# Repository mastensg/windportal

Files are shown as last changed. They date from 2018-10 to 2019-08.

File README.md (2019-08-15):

# Windportal
An interactive installation demonstrating the power of the wind.

The machine simulates the wind conditions at the Hywind off-shore windmill part in Scotland.
Live data about current windspeed conditions are fetched, and the audience can press a button
to experience this wind-power blowing in their face.

Developed for Equinor in collaboration with ad-agency [Dept](http://dept.no).

[More info, pictures and video](https://dept.no/project/equinor-wind-portal)

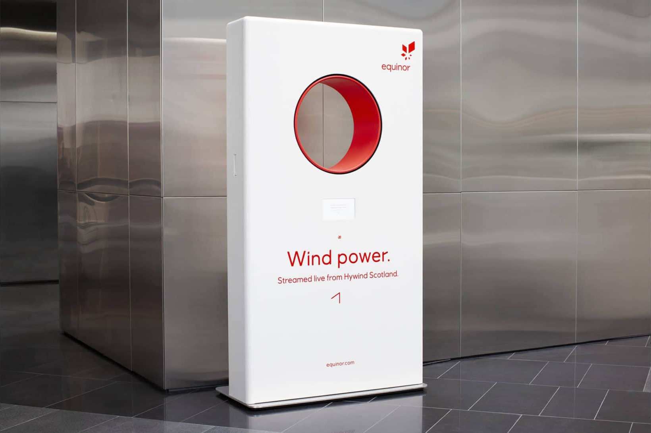
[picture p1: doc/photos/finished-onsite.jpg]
Finished windportal


## Contents
This repo contains the software and electronics of the system,
developed by Martin Stensgård and [Jon Nordby](http://jonnor.com).

A previous iteration can be found at [jonnor/windportal](https://github.com/jonnor/windportal).

## License
[ISC](./LICENSE.md)

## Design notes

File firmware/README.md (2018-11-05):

## SSH config
To jump via the central cloud server.

    Host windhub
	    HostName hub.wind.mastensg.net
	    User jonnor
    
    Host wind0
     	User jonnor
    #	HostName  dlock-dev.local
	    ProxyCommand=ssh windhub nc localhost 2000

## Initalize device from base image

On first run you need to use default `pi` user. This should only be done on a private Ethernet connection.

    ansible-playbook display.yml -l display0 --user pi --ask-pass

Afterwards the SSH keys are in place

    ansible-playbook display.yml -l display0

## Flash base image

    gunzip -c display0-raspbian.img | sudo dd of=/dev/MYSCARD status=progress oflag=sync bs=1M

## Make base image
To make something flashable of a known size (under 4GB) with a known hostname.

* Download Raspbian https://www.raspberrypi.org/downloads/raspbian/
* Flash onto SD card `unzip -p raspbian_lite_latest 2018-10-09-raspbian-stretch-lite.img | dd of=/dev/MYCARD bs=1M`
* Mount `/` filesytem, change hostname and hosts to `display0`
* Enable workstation in `/etc/avahi-daemon.conf`: `publish-workstation=yes`
* Mount `/boot` filesyste. Add empty `ssh` file to enable SSH
* Add `enable_uart=1` and `dtoverlay=pi3-disable-bt` to `/boot/config.txt` for serial console
* Put SDCard into RPi, connect Ethernet cable to PC
* Boot RPi, check that you can SSH into it `ssh pi@display0.local`
* Check that automatic partition resizing was completed
* Turn of RPI, put SDcard into PC
* Resize root filesystem to 3000M with `resize2fs`
* Resize root partition to 3100M with `cfdisk`
* Make image using `dd if=/dev/mmcblk1 conv=sync,noerror bs=1M count=8k | gzip -c > display0-raspbian.img.gz`

## Environment variables

Some programs require variables to be set to work.

    MSGFLO_BROKER={{display_broker_url}}
    DISPLAY_PREFIX=display/{{ansible_hostname}}
    WP_FONT_PATH=/opt/windmachine/equinor_fonts/Equinor-Medium.otf

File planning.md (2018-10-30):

Key questions

- [x] OK with FOSS (Sjur)
- [x] Fan control interface. Analog or modbus
- [x] Decide display. LCD, dial indicator or 7-segment.
- [x] Get a custom domain (dep: Sjur) `windportal.dept.no`
- [ ] Ownership server,SIM (dep: Sjur)

Risk moments

- Interfacing fan,display
- Data communication device,server,datasource
- In-field failures

Bugs

- [ ] If Arduino is unplugged, wp_firmata keeps running using 100% CPU.
- [ ] ssh-call-home sometimes hangs, does not reconnect after network or server disconnect

Tools

- [ ] CLI for sending IPC message `wp_ipc KEY VALUE`

## Deadlines

### Tuesday 16 October
- Specification frozen.
- Decided display type
- All electronics/hardware ordered.

## Done

Kickoff

- [x] Estimate hours / cost for project

Milestone 0: Ready to work

- [x] Copy Ansible skeleton (J) 5
- [x] Setup RPi3b+ base (J)
- [x] Setup firmware base (J)
- [x] Setup server. Linode,DNS,email,Mosquitto in Ansible (M) 5
- [x] Server is deployed

RPI ready

- [x] RPI automatically sets up reverse SSH (J)
- [x] Setup/test 3G modem on RPI (J)
- [x] Device can fetch current wind data from server (J)
- [x] Test Firmata at same time as ModemManager, ttyACMx. (J)

Milestone FANCONTROL:

- [x] Tested control of fan from software (via Firmata, analog/PWM) 

Control panel

- [x] Status LEDs
- [x] Potmeter animation scale
- [x] Potmeter manual fan control
- [x] Software/manual switch

Milestone B: All electronics assembled (M)

- [x] Baseboard for mounting in box
- [x] Optocoupler for fancontrol. Non-inverting
- [x] USB to serial in dashboard
- [x] RPi powered and running
- [x] Arduino with daughterboard
- [x] Display connected
- [x] Fan power module connected

## TODO

### System check, Oct 23

Documentation

- [x] Make block diagram of electronics

Windgust animation

- [x] First version. Should depend on (average) windspeed
- [x] Move animation to dedicated program (J)
- [x] systemd/Ansible for services (J)

Display:

- [x] Test servocontrol for dial type display. Incl a simple hand. (M)
- [x] Screen tested OK
- [x] Program to display windspeed

Milestone C: I/O complete, from RPi (M)

- [x] Get adjust potentiometer (power level)
- [x] Set fan power
- [x] Show text on display

Server datafetching

- [x] Define MQTT interface (J)
- [x] Server fetches data using YR (J) 3
- [x] Fetch data using scraped HTML page (J) 3
- [x] Deploy data fetcher to hub

## Assembly, Friday Oct 26

Electronics

- [x] Buy power supplies. 5V + 12V
- [x] Buy enclosure(s) PSU
- [x] Buy Wago connectors
- [x] Use cable glands on wires
- [x] Add USB powered hub
- [x] Solder the serial console connection

User button

- [x] Test user button input
- [x] Firmata: get user button status (turn on)
- [x] Scale gusts based on user input

Display

- [x] Add wind description label "frisk bris" under windspeed
- [x] Add a small variation to shown windspeed
- [ ] Hide startup rainbow, linux messages from screen
- [ ] Hide low-power symbol

## Tuneup

Bugs

- [ ] Firmata process sometimes hangs.
Possibly due to blocking write() call if discovery is not successful.
Use systemd watchdog to make sure it restarts. https://stackoverflow.com/a/37111518/1967571

Monitoring

- [ ] Turn status LEDs in panel on/off
- [ ] Log 4G status. Signal strength, network type, connected/not
- [ ] Log undervoltage condition. Ideally voltage level, or just dmesg warnings
- [ ] Device reports heartbeat to server on MQTT (`fbp`)
- [ ] Server stores heartbeat events

System complete checklist

- [ ] Windgust animation works
- [ ] Monitoring exists
- [ ] Tested device poweroffs
- [ ] Tested device disconnect/reconnect
- [ ] Tested server downtime, recovers automatically
- [ ] Tested windpower override switch

## Failure modes

- I/O failure. Software does right thing, but right action does not happen
- RPi fails to fetch server. 3G connection, HTTP error, server down
- [...]

## Worklog

Date,person,hours,area

    02.10.2018,jon,8,planning
    02.10.2018,martin,8,planning
    03.10.2018,jon,2,firmware
    07.10.2018,jon,4,firmware
    09.10.2018,jon,1,planning
    09.10.2018,jon,4,io

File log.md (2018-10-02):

- [ ] hvilke servo-motorer? hvor mye dreiemoment?

--------------------------------  2018-10-02  --------------------------------

møte hos adep
- martin
- jacob
- sjur
- petter
- jonnor

--------------------------

hvor mye dreiemoment?

vi kan teste med 5.5 kgcm servo

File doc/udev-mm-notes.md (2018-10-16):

## serial device internal on RPI

jonnor@display0:~ $ udevadm info -a --name /dev/ttyAMA0

Udevadm info starts with the device specified by the devpath and then
walks up the chain of parent devices. It prints for every device
found, all possible attributes in the udev rules key format.
A rule to match, can be composed by the attributes of the device
and the attributes from one single parent device.

  looking at device '/devices/platform/soc/3f201000.serial/tty/ttyAMA0':
    KERNEL=="ttyAMA0"
    SUBSYSTEM=="tty"
    DRIVER==""

  looking at parent device '/devices/platform/soc/3f201000.serial':
    KERNELS=="3f201000.serial"
    SUBSYSTEMS=="amba"
    DRIVERS=="uart-pl011"
    ATTRS{driver_override}=="(null)"
    ATTRS{id}=="00241011"
    ATTRS{irq0}=="87"

  looking at parent device '/devices/platform/soc':
    KERNELS=="soc"
    SUBSYSTEMS=="platform"
    DRIVERS==""
    ATTRS{driver_override}=="(null)"

  looking at parent device '/devices/platform':
    KERNELS=="platform"
    SUBSYSTEMS==""
    DRIVERS==""

    jonnor@display0:~ $ udevadm info --query=property /dev/ttyAMA0
    DEVLINKS=/dev/serial1
    DEVNAME=/dev/ttyAMA0
    DEVPATH=/devices/platform/soc/3f201000.serial/tty/ttyAMA0
    ID_MM_CANDIDATE=1
    MAJOR=204
    MINOR=64
    SUBSYSTEM=tty
    TAGS=:systemd:
    USEC_INITIALIZED=3899475

## Arduino Leonardo

jonnor@display0:~ $ udevadm monitor
monitor will print the received events for:
UDEV - the event which udev sends out after rule processing
KERNEL - the kernel uevent

KERNEL[785.479930] add      /devices/platform/soc/3f980000.usb/usb1/1-1/1-1.3 (usb)
KERNEL[785.481021] add      /devices/platform/soc/3f980000.usb/usb1/1-1/1-1.3/1-1.3:1.0 (usb)
KERNEL[785.481991] add      /devices/platform/soc/3f980000.usb/usb1/1-1/1-1.3/1-1.3:1.1 (usb)
UDEV  [785.510745] add      /devices/platform/soc/3f980000.usb/usb1/1-1/1-1.3 (usb)
UDEV  [785.521791] add      /devices/platform/soc/3f980000.usb/usb1/1-1/1-1.3/1-1.3:1.1 (usb)
KERNEL[785.526125] add      /module/cdc_acm (module)
KERNEL[785.528409] add      /devices/platform/soc/3f980000.usb/usb1/1-1/1-1.3/1-1.3:1.0/tty/ttyACM0 (tty)
KERNEL[785.528593] add      /bus/usb/drivers/cdc_acm (drivers)
UDEV  [785.528899] add      /devices/platform/soc/3f980000.usb/usb1/1-1/1-1.3/1-1.3:1.0 (usb)
UDEV  [785.530816] add      /module/cdc_acm (module)
UDEV  [785.535533] add      /bus/usb/drivers/cdc_acm (drivers)
UDEV  [785.541592] add      /devices/platform/soc/3f980000.usb/usb1/1-1/1-1.3/1-1.3:1.0/tty/ttyACM0 (tty)
^Cjonnor@display0:~ $ udevadm info -a --name /dev/ttyACM0 --query=all
P: /devices/platform/soc/3f980000.usb/usb1/1-1/1-1.3/1-1.3:1.0/tty/ttyACM0
N: ttyACM0
S: serial/by-id/usb-Arduino_LLC_Arduino_Leonardo-if00
S: serial/by-path/platform-3f980000.usb-usb-0:1.3:1.0
E: DEVLINKS=/dev/serial/by-id/usb-Arduino_LLC_Arduino_Leonardo-if00 /dev/serial/by-path/platform-3f980000.usb-usb-0:1.3:1.0
E: DEVNAME=/dev/ttyACM0
E: DEVPATH=/devices/platform/soc/3f980000.usb/usb1/1-1/1-1.3/1-1.3:1.0/tty/ttyACM0
E: ID_BUS=usb
E: ID_MM_CANDIDATE=1
E: ID_MODEL=Arduino_Leonardo
E: ID_MODEL_ENC=Arduino\x20Leonardo
E: ID_MODEL_FROM_DATABASE=Leonardo (CDC ACM, HID)
E: ID_MODEL_ID=8036
E: ID_PATH=platform-3f980000.usb-usb-0:1.3:1.0
E: ID_PATH_TAG=platform-3f980000_usb-usb-0_1_3_1_0
E: ID_REVISION=0100
E: ID_SERIAL=Arduino_LLC_Arduino_Leonardo
E: ID_TYPE=generic
E: ID_USB_CLASS_FROM_DATABASE=Miscellaneous Device
E: ID_USB_DRIVER=cdc_acm
E: ID_USB_INTERFACES=:020200:0a0000:
E: ID_USB_INTERFACE_NUM=00
E: ID_USB_PROTOCOL_FROM_DATABASE=Interface Association
E: ID_VENDOR=Arduino_LLC
E: ID_VENDOR_ENC=Arduino\x20LLC
E: ID_VENDOR_FROM_DATABASE=Arduino SA
E: ID_VENDOR_ID=2341
E: MAJOR=166
E: MINOR=0
E: SUBSYSTEM=tty
E: TAGS=:systemd:
E: USEC_INITIALIZED=785540456

jonnor@display0:~ $ udevadm info -a --name /dev/ttyACM0

## Not connecting

Oct 16 18:10:15 display0 ModemManager[297]: <info>  Simple connect started...
Oct 16 18:10:15 display0 ModemManager[297]: <info>  Simple connect state (4/8): Wait to get fully enabled
Oct 16 18:10:15 display0 ModemManager[297]: <info>  Simple connect state (5/8): Register
Oct 16 18:10:15 display0 ModemManager[297]: <info>  Simple connect state (6/8): Bearer
Oct 16 18:10:15 display0 ModemManager[297]: <info>  Simple connect state (7/8): Connect
Oct 16 18:10:15 display0 ModemManager[297]: <info>  Modem /org/freedesktop/ModemManager1/Modem/1: state changed (registered -> connecting)
Oct 16 18:10:15 display0 ModemManager[297]: <warn>  (ttyUSB1): port attributes not fully set

Udevadm info starts with the device specified by the devpath and then
walks up the chain of parent devices. It prints for every device
found, all possible attributes in the udev rules key format.
A rule to match, can be composed by the attributes of the device
and the attributes from one single parent device.

  looking at device '/devices/platform/soc/3f980000.usb/usb1/1-1/1-1.3/1-1.3:1.0/tty/ttyACM0':
    KERNEL=="ttyACM0"
    SUBSYSTEM=="tty"
    DRIVER==""

  looking at parent device '/devices/platform/soc/3f980000.usb/usb1/1-1/1-1.3/1-1.3:1.0':
    KERNELS=="1-1.3:1.0"
    SUBSYSTEMS=="usb"
    DRIVERS=="cdc_acm"
    ATTRS{authorized}=="1"
    ATTRS{bAlternateSetting}==" 0"
    ATTRS{bInterfaceClass}=="02"
    ATTRS{bInterfaceNumber}=="00"
    ATTRS{bInterfaceProtocol}=="00"
    ATTRS{bInterfaceSubClass}=="02"
    ATTRS{bNumEndpoints}=="01"
    ATTRS{bmCapabilities}=="6"
    ATTRS{iad_bFirstInterface}=="00"
    ATTRS{iad_bFunctionClass}=="02"
    ATTRS{iad_bFunctionProtocol}=="01"
    ATTRS{iad_bFunctionSubClass}=="02"
    ATTRS{iad_bInterfaceCount}=="02"
    ATTRS{supports_autosuspend}=="1"

  looking at parent device '/devices/platform/soc/3f980000.usb/usb1/1-1/1-1.3':
    KERNELS=="1-1.3"
    SUBSYSTEMS=="usb"
    DRIVERS=="usb"
    ATTRS{authorized}=="1"
    ATTRS{avoid_reset_quirk}=="0"
    ATTRS{bConfigurationValue}=="1"
    ATTRS{bDeviceClass}=="ef"
    ATTRS{bDeviceProtocol}=="01"
    ATTRS{bDeviceSubClass}=="02"
    ATTRS{bMaxPacketSize0}=="64"
    ATTRS{bMaxPower}=="500mA"
    ATTRS{bNumConfigurations}=="1"
    ATTRS{bNumInterfaces}==" 2"
    ATTRS{bcdDevice}=="0100"
    ATTRS{bmAttributes}=="a0"
    ATTRS{busnum}=="1"
    ATTRS{configuration}==""
    ATTRS{devnum}=="5"
    ATTRS{devpath}=="1.3"
    ATTRS{devspec}=="  (null)"
    ATTRS{idProduct}=="8036"
    ATTRS{idVendor}=="2341"
    ATTRS{ltm_capable}=="no"
    ATTRS{manufacturer}=="Arduino LLC"
    ATTRS{maxchild}=="0"
    ATTRS{product}=="Arduino Leonardo"
    ATTRS{quirks}=="0x0"
    ATTRS{removable}=="removable"
    ATTRS{speed}=="12"
    ATTRS{urbnum}=="276"
    ATTRS{version}==" 2.00"

  looking at parent device '/devices/platform/soc/3f980000.usb/usb1/1-1':
    KERNELS=="1-1"
    SUBSYSTEMS=="usb"
    DRIVERS=="usb"
    ATTRS{authorized}=="1"
    ATTRS{avoid_reset_quirk}=="0"
    ATTRS{bConfigurationValue}=="1"
    ATTRS{bDeviceClass}=="09"
    ATTRS{bDeviceProtocol}=="02"
    ATTRS{bDeviceSubClass}=="00"
    ATTRS{bMaxPacketSize0}=="64"
    ATTRS{bMaxPower}=="2mA"
    ATTRS{bNumConfigurations}=="1"
    ATTRS{bNumInterfaces}==" 1"
    ATTRS{bcdDevice}=="0bb3"
    ATTRS{bmAttributes}=="e0"
    ATTRS{busnum}=="1"
    ATTRS{configuration}==""
    ATTRS{devnum}=="2"
    ATTRS{devpath}=="1"
    ATTRS{idProduct}=="2514"
    ATTRS{idVendor}=="0424"
    ATTRS{ltm_capable}=="no"
    ATTRS{maxchild}=="4"
    ATTRS{quirks}=="0x0"
    ATTRS{removable}=="unknown"
    ATTRS{speed}=="480"
    ATTRS{urbnum}=="53"
    ATTRS{version}==" 2.00"

  looking at parent device '/devices/platform/soc/3f980000.usb/usb1':
    KERNELS=="usb1"
    SUBSYSTEMS=="usb"
    DRIVERS=="usb"
    ATTRS{authorized}=="1"
    ATTRS{authorized_default}=="1"
    ATTRS{avoid_reset_quirk}=="0"
    ATTRS{bConfigurationValue}=="1"
    ATTRS{bDeviceClass}=="09"
    ATTRS{bDeviceProtocol}=="01"
    ATTRS{bDeviceSubClass}=="00"
    ATTRS{bMaxPacketSize0}=="64"
    ATTRS{bMaxPower}=="0mA"
    ATTRS{bNumConfigurations}=="1"
    ATTRS{bNumInterfaces}==" 1"
    ATTRS{bcdDevice}=="0414"
    ATTRS{bmAttributes}=="e0"
    ATTRS{busnum}=="1"
    ATTRS{configuration}==""
    ATTRS{devnum}=="1"
    ATTRS{devpath}=="0"
    ATTRS{idProduct}=="0002"
    ATTRS{idVendor}=="1d6b"
    ATTRS{interface_authorized_default}=="1"
    ATTRS{ltm_capable}=="no"
    ATTRS{manufacturer}=="Linux 4.14.71-v7+ dwc_otg_hcd"
    ATTRS{maxchild}=="1"
    ATTRS{product}=="DWC OTG Controller"
    ATTRS{quirks}=="0x0"
    ATTRS{removable}=="unknown"
    ATTRS{serial}=="3f980000.usb"
    ATTRS{speed}=="480"
    ATTRS{urbnum}=="31"
    ATTRS{version}==" 2.00"

  looking at parent device '/devices/platform/soc/3f980000.usb':
    KERNELS=="3f980000.usb"
    SUBSYSTEMS=="platform"
    DRIVERS=="dwc_otg"
    ATTRS{busconnected}=="Bus Connected = 0x1"
    ATTRS{buspower}=="Bus Power = 0x1"
    ATTRS{bussuspend}=="Bus Suspend = 0x0"
    ATTRS{devspeed}=="Device Speed = 0x0"
    ATTRS{driver_override}=="(null)"
    ATTRS{enumspeed}=="Device Enumeration Speed = 0x1"
    ATTRS{fr_interval}=="Frame Interval = 0x1d4b"
    ATTRS{ggpio}=="GGPIO = 0x00000000"
    ATTRS{gnptxfsiz}=="GNPTXFSIZ = 0x01000306"
    ATTRS{gotgctl}=="GOTGCTL = 0x001c0000"
    ATTRS{gpvndctl}=="GPVNDCTL = 0x00000000"
    ATTRS{grxfsiz}=="GRXFSIZ = 0x00000306"
    ATTRS{gsnpsid}=="GSNPSID = 0x4f54280a"
    ATTRS{guid}=="GUID = 0x2708a000"
    ATTRS{gusbcfg}=="GUSBCFG = 0x20001700"
    ATTRS{hcd_frrem}=="HCD Dump Frame Remaining"
    ATTRS{hcddump}=="HCD Dump"
    ATTRS{hnp}=="HstNegScs = 0x0"
    ATTRS{hnpcapable}=="HNPCapable = 0x1"
    ATTRS{hprt0}=="HPRT0 = 0x00001005"
    ATTRS{hptxfsiz}=="HPTXFSIZ = 0x02000406"
    ATTRS{hsic_connect}=="HSIC Connect = 0x1"
    ATTRS{inv_sel_hsic}=="Invert Select HSIC = 0x0"
    ATTRS{mode}=="Mode = 0x1"
    ATTRS{mode_ch_tim_en}=="Mode Change Ready Timer Enable = 0x0"
    ATTRS{rd_reg_test}=="Time to read GNPTXFSIZ reg 10000000 times: 1770 msecs (177 jiffies)"
    ATTRS{regdump}=="Register Dump"
    ATTRS{regoffset}=="0xffffffff"
    ATTRS{regvalue}=="invalid offset"
    ATTRS{rem_wakeup_pwrdn}==""
    ATTRS{remote_wakeup}=="Remote Wakeup Sig = 0 Enabled = 0 LPM Remote Wakeup = 0"
    ATTRS{spramdump}=="SPRAM Dump"
    ATTRS{srp}=="SesReqScs = 0x0"
    ATTRS{srpcapable}=="SRPCapable = 0x1"
    ATTRS{wr_reg_test}=="Time to write GNPTXFSIZ reg 10000000 times: 320 msecs (32 jiffies)"

  looking at parent device '/devices/platform/soc':
    KERNELS=="soc"
    SUBSYSTEMS=="platform"
    DRIVERS==""
    ATTRS{driver_override}=="(null)"

  looking at parent device '/devices/platform':
    KERNELS=="platform"
    SUBSYSTEMS==""
    DRIVERS==""

## 4G modem

jonnor@display0:~ $ udevadm monitor
monitor will print the received events for:
UDEV - the event which udev sends out after rule processing
KERNEL - the kernel uevent

KERNEL[890.422815] add      /devices/platform/soc/3f980000.usb/usb1/1-1/1-1.2 (usb)
KERNEL[890.485129] add      /devices/platform/soc/3f980000.usb/usb1/1-1/1-1.2/1-1.2:1.0 (usb)
KERNEL[890.486846] add      /devices/platform/soc/3f980000.usb/usb1/1-1/1-1.2/1-1.2:1.0/host0 (scsi)
KERNEL[890.487033] add      /devices/platform/soc/3f980000.usb/usb1/1-1/1-1.2/1-1.2:1.0/host0/scsi_host/host0 (scsi_host)
UDEV  [890.525196] add      /devices/platform/soc/3f980000.usb/usb1/1-1/1-1.2 (usb)

UDEV  [890.625184] add      /devices/platform/soc/3f980000.usb/usb1/1-1/1-1.2/1-1.2:1.0 (usb)
UDEV  [890.628709] add      /devices/platform/soc/3f980000.usb/usb1/1-1/1-1.2/1-1.2:1.0/host0 (scsi)
UDEV  [890.632169] add      /devices/platform/soc/3f980000.usb/usb1/1-1/1-1.2/1-1.2:1.0/host0/scsi_host/host0 (scsi_host)
KERNEL[891.221433] remove   /devices/platform/soc/3f980000.usb/usb1/1-1/1-1.2/1-1.2:1.0/host0/scsi_host/host0 (scsi_host)
KERNEL[891.222620] remove   /devices/platform/soc/3f980000.usb/usb1/1-1/1-1.2/1-1.2:1.0/host0 (scsi)
UDEV  [891.223584] remove   /devices/platform/soc/3f980000.usb/usb1/1-1/1-1.2/1-1.2:1.0/host0/scsi_host/host0 (scsi_host)
UDEV  [891.224100] remove   /devices/platform/soc/3f980000.usb/usb1/1-1/1-1.2/1-1.2:1.0/host0 (scsi)
KERNEL[891.534158] remove   /devices/platform/soc/3f980000.usb/usb1/1-1/1-1.2/1-1.2:1.0 (usb)
KERNEL[891.535558] remove   /devices/platform/soc/3f980000.usb/usb1/1-1/1-1.2 (usb)
UDEV  [891.538819] remove   /devices/platform/soc/3f980000.usb/usb1/1-1/1-1.2/1-1.2:1.0 (usb)
UDEV  [891.541997] remove   /devices/platform/soc/3f980000.usb/usb1/1-1/1-1.2 (usb)
KERNEL[892.112520] add      /devices/platform/soc/3f980000.usb/usb1/1-1/1-1.2 (usb)
KERNEL[892.175345] add      /devices/platform/soc/3f980000.usb/usb1/1-1/1-1.2/1-1.2:1.0 (usb)
KERNEL[892.175591] add      /devices/platform/soc/3f980000.usb/usb1/1-1/1-1.2/1-1.2:1.1 (usb)
KERNEL[892.176247] add      /devices/platform/soc/3f980000.usb/usb1/1-1/1-1.2/1-1.2:1.2 (usb)
KERNEL[892.177231] add      /devices/platform/soc/3f980000.usb/usb1/1-1/1-1.2/1-1.2:1.3 (usb)
KERNEL[892.178595] add      /devices/platform/soc/3f980000.usb/usb1/1-1/1-1.2/1-1.2:1.3/host0 (scsi)
KERNEL[892.178760] add      /devices/platform/soc/3f980000.usb/usb1/1-1/1-1.2/1-1.2:1.3/host0/scsi_host/host0 (scsi_host)
KERNEL[892.179371] add      /devices/platform/soc/3f980000.usb/usb1/1-1/1-1.2/1-1.2:1.4 (usb)
KERNEL[892.184697] add      /devices/platform/soc/3f980000.usb/usb1/1-1/1-1.2/1-1.2:1.4/host1 (scsi)
KERNEL[892.184878] add      /devices/platform/soc/3f980000.usb/usb1/1-1/1-1.2/1-1.2:1.4/host1/scsi_host/host1 (scsi_host)
UDEV  [892.257261] add      /devices/platform/soc/3f980000.usb/usb1/1-1/1-1.2 (usb)
UDEV  [892.274844] add      /devices/platform/soc/3f980000.usb/usb1/1-1/1-1.2/1-1.2:1.4 (usb)
KERNEL[892.278015] add      /module/usbserial (module)
KERNEL[892.278256] add      /bus/usb-serial (bus)
KERNEL[892.278371] add      /bus/usb/drivers/usbserial (drivers)
KERNEL[892.278503] add      /bus/usb/drivers/usbserial_generic (drivers)
KERNEL[892.278627] add      /bus/usb-serial/drivers/generic (drivers)
KERNEL[892.281855] add      /module/cdc_ncm (module)
KERNEL[892.282149] add      /bus/usb/drivers/cdc_ncm (drivers)
KERNEL[892.283416] add      /module/usb_wwan (module)
KERNEL[892.285813] add      /module/cdc_wdm (module)
KERNEL[892.286000] add      /bus/usb/drivers/cdc_wdm (drivers)
UDEV  [892.295627] add      /bus/usb-serial (bus)
UDEV  [892.296264] add      /devices/platform/soc/3f980000.usb/usb1/1-1/1-1.2/1-1.2:1.4/host1 (scsi)
UDEV  [892.296591] add      /devices/platform/soc/3f980000.usb/usb1/1-1/1-1.2/1-1.2:1.3 (usb)
UDEV  [892.297199] add      /module/usbserial (module)
KERNEL[892.298153] add      /module/huawei_cdc_ncm (module)
UDEV  [892.303886] add      /module/cdc_ncm (module)
UDEV  [892.306884] add      /devices/platform/soc/3f980000.usb/usb1/1-1/1-1.2/1-1.2:1.4/host1/scsi_host/host1 (scsi_host)
KERNEL[892.307621] add      /module/option (module)
KERNEL[892.307770] add      /bus/usb/drivers/option (drivers)
UDEV  [892.308091] add      /devices/platform/soc/3f980000.usb/usb1/1-1/1-1.2/1-1.2:1.3/host0 (scsi)
KERNEL[892.308664] add      /bus/usb-serial/drivers/option1 (drivers)
UDEV  [892.312162] add      /bus/usb/drivers/usbserial_generic (drivers)
UDEV  [892.313157] add      /module/cdc_wdm (module)
UDEV  [892.317561] add      /module/huawei_cdc_ncm (module)
UDEV  [892.318239] add      /bus/usb/drivers/cdc_wdm (drivers)
UDEV  [892.318459] add      /bus/usb-serial/drivers/generic (drivers)
UDEV  [892.320194] add      /bus/usb/drivers/cdc_ncm (drivers)
UDEV  [892.321433] add      /module/usb_wwan (module)
UDEV  [892.325736] add      /bus/usb/drivers/option (drivers)
UDEV  [892.326747] add      /bus/usb-serial/drivers/option1 (drivers)
UDEV  [892.328542] add      /bus/usb/drivers/usbserial (drivers)
UDEV  [892.330215] add      /module/option (module)
UDEV  [892.334218] add      /devices/platform/soc/3f980000.usb/usb1/1-1/1-1.2/1-1.2:1.3/host0/scsi_host/host0 (scsi_host)
KERNEL[892.412795] add      /class/usbmisc (class)
KERNEL[892.412936] add      /devices/platform/soc/3f980000.usb/usb1/1-1/1-1.2/1-1.2:1.2/usbmisc/cdc-wdm0 (usbmisc)
KERNEL[892.413414] add      /devices/platform/soc/3f980000.usb/usb1/1-1/1-1.2/1-1.2:1.2/net/wwan0 (net)
KERNEL[892.413513] add      /devices/platform/soc/3f980000.usb/usb1/1-1/1-1.2/1-1.2:1.2/net/wwan0/queues/rx-0 (queues)
KERNEL[892.413563] add      /devices/platform/soc/3f980000.usb/usb1/1-1/1-1.2/1-1.2:1.2/net/wwan0/queues/tx-0 (queues)
KERNEL[892.413617] add      /bus/usb/drivers/huawei_cdc_ncm (drivers)
UDEV  [892.413917] add      /devices/platform/soc/3f980000.usb/usb1/1-1/1-1.2/1-1.2:1.2 (usb)
KERNEL[892.414575] add      /devices/platform/soc/3f980000.usb/usb1/1-1/1-1.2/1-1.2:1.0/ttyUSB0 (usb-serial)
KERNEL[892.414701] add      /devices/platform/soc/3f980000.usb/usb1/1-1/1-1.2/1-1.2:1.0/ttyUSB0/tty/ttyUSB0 (tty)
KERNEL[892.414769] add      /devices/platform/soc/3f980000.usb/usb1/1-1/1-1.2/1-1.2:1.1/ttyUSB1 (usb-serial)
KERNEL[892.415367] add      /devices/platform/soc/3f980000.usb/usb1/1-1/1-1.2/1-1.2:1.1/ttyUSB1/tty/ttyUSB1 (tty)
UDEV  [892.415521] add      /devices/platform/soc/3f980000.usb/usb1/1-1/1-1.2/1-1.2:1.1 (usb)
UDEV  [892.416177] add      /devices/platform/soc/3f980000.usb/usb1/1-1/1-1.2/1-1.2:1.0 (usb)
UDEV  [892.416449] add      /class/usbmisc (class)
UDEV  [892.420099] add      /devices/platform/soc/3f980000.usb/usb1/1-1/1-1.2/1-1.2:1.0/ttyUSB0 (usb-serial)
UDEV  [892.421726] add      /devices/platform/soc/3f980000.usb/usb1/1-1/1-1.2/1-1.2:1.1/ttyUSB1 (usb-serial)
UDEV  [892.423616] add      /bus/usb/drivers/huawei_cdc_ncm (drivers)
UDEV  [892.428848] add      /devices/platform/soc/3f980000.usb/usb1/1-1/1-1.2/1-1.2:1.2/usbmisc/cdc-wdm0 (usbmisc)
UDEV  [892.461268] add      /devices/platform/soc/3f980000.usb/usb1/1-1/1-1.2/1-1.2:1.0/ttyUSB0/tty/ttyUSB0 (tty)
UDEV  [892.465756] add      /devices/platform/soc/3f980000.usb/usb1/1-1/1-1.2/1-1.2:1.1/ttyUSB1/tty/ttyUSB1 (tty)
UDEV  [892.476228] add      /devices/platform/soc/3f980000.usb/usb1/1-1/1-1.2/1-1.2:1.2/net/wwan0 (net)
UDEV  [892.483090] add      /devices/platform/soc/3f980000.usb/usb1/1-1/1-1.2/1-1.2:1.2/net/wwan0/queues/tx-0 (queues)
UDEV  [892.483813] add      /devices/platform/soc/3f980000.usb/usb1/1-1/1-1.2/1-1.2:1.2/net/wwan0/queues/rx-0 (queues)
KERNEL[893.201550] add      /devices/platform/soc/3f980000.usb/usb1/1-1/1-1.2/1-1.2:1.3/host0/target0:0:0 (scsi)
KERNEL[893.201794] add      /devices/platform/soc/3f980000.usb/usb1/1-1/1-1.2/1-1.2:1.3/host0/target0:0:0/0:0:0:0 (scsi)
KERNEL[893.201964] add      /devices/platform/soc/3f980000.usb/usb1/1-1/1-1.2/1-1.2:1.3/host0/target0:0:0/0:0:0:0/scsi_device/0:0:0:0 (scsi_device)
KERNEL[893.203686] add      /devices/platform/soc/3f980000.usb/usb1/1-1/1-1.2/1-1.2:1.4/host1/target1:0:0 (scsi)
KERNEL[893.203866] add      /devices/platform/soc/3f980000.usb/usb1/1-1/1-1.2/1-1.2:1.4/host1/target1:0:0/1:0:0:0 (scsi)
KERNEL[893.204012] add      /devices/platform/soc/3f980000.usb/usb1/1-1/1-1.2/1-1.2:1.4/host1/target1:0:0/1:0:0:0/scsi_disk/1:0:0:0 (scsi_disk)
KERNEL[893.204223] add      /devices/platform/soc/3f980000.usb/usb1/1-1/1-1.2/1-1.2:1.4/host1/target1:0:0/1:0:0:0/scsi_device/1:0:0:0 (scsi_device)
KERNEL[893.206090] add      /devices/platform/soc/3f980000.usb/usb1/1-1/1-1.2/1-1.2:1.3/host0/target0:0:0/0:0:0:0/bsg/0:0:0:0 (bsg)
KERNEL[893.206771] add      /devices/platform/soc/3f980000.usb/usb1/1-1/1-1.2/1-1.2:1.4/host1/target1:0:0/1:0:0:0/bsg/1:0:0:0 (bsg)
KERNEL[893.207913] add      /devices/virtual/bdi/8:0 (bdi)
KERNEL[893.208562] add      /devices/platform/soc/3f980000.usb/usb1/1-1/1-1.2/1-1.2:1.4/host1/target1:0:0/1:0:0:0/block/sda (block)
KERNEL[893.215062] change   /devices/platform/soc/3f980000.usb/usb1/1-1/1-1.2/1-1.2:1.4/host1/target1:0:0/1:0:0:0/block/sda (block)
UDEV  [893.215710] add      /devices/platform/soc/3f980000.usb/usb1/1-1/1-1.2/1-1.2:1.3/host0/target0:0:0 (scsi)
UDEV  [893.216120] add      /devices/virtual/bdi/8:0 (bdi)
UDEV  [893.221402] add      /devices/platform/soc/3f980000.usb/usb1/1-1/1-1.2/1-1.2:1.4/host1/target1:0:0 (scsi)
KERNEL[893.227185] add      /module/sg (module)
KERNEL[893.227357] add      /class/scsi_generic (class)
KERNEL[893.229634] add      /devices/platform/soc/3f980000.usb/usb1/1-1/1-1.2/1-1.2:1.3/host0/target0:0:0/0:0:0:0/scsi_generic/sg0 (scsi_generic)
KERNEL[893.230695] add      /devices/platform/soc/3f980000.usb/usb1/1-1/1-1.2/1-1.2:1.4/host1/target1:0:0/1:0:0:0/scsi_generic/sg1 (scsi_generic)
UDEV  [893.231045] add      /module/sg (module)
UDEV  [893.232640] add      /devices/platform/soc/3f980000.usb/usb1/1-1/1-1.2/1-1.2:1.4/host1/target1:0:0/1:0:0:0 (scsi)
UDEV  [893.238934] add      /class/scsi_generic (class)
UDEV  [893.243572] add      /devices/platform/soc/3f980000.usb/usb1/1-1/1-1.2/1-1.2:1.4/host1/target1:0:0/1:0:0:0/scsi_device/1:0:0:0 (scsi_device)
KERNEL[893.244850] add      /module/cdrom (module)
UDEV  [893.249239] add      /module/cdrom (module)
KERNEL[893.249423] add      /module/sr_mod (module)
UDEV  [893.250084] add      /devices/platform/soc/3f980000.usb/usb1/1-1/1-1.2/1-1.2:1.4/host1/target1:0:0/1:0:0:0/scsi_disk/1:0:0:0 (scsi_disk)
KERNEL[893.251542] add      /devices/virtual/bdi/11:0 (bdi)
KERNEL[893.251867] add      /devices/platform/soc/3f980000.usb/usb1/1-1/1-1.2/1-1.2:1.3/host0/target0:0:0/0:0:0:0/block/sr0 (block)
KERNEL[893.252266] add      /bus/scsi/drivers/sr (drivers)
UDEV  [893.252574] add      /devices/platform/soc/3f980000.usb/usb1/1-1/1-1.2/1-1.2:1.3/host0/target0:0:0/0:0:0:0 (scsi)
KERNEL[893.253322] change   /devices/platform/soc/3f980000.usb/usb1/1-1/1-1.2/1-1.2:1.3/host0/target0:0:0/0:0:0:0/block/sr0 (block)
UDEV  [893.254731] add      /module/sr_mod (module)
UDEV  [893.256853] add      /devices/virtual/bdi/11:0 (bdi)
UDEV  [893.261433] add      /bus/scsi/drivers/sr (drivers)
UDEV  [893.261548] add      /devices/platform/soc/3f980000.usb/usb1/1-1/1-1.2/1-1.2:1.3/host0/target0:0:0/0:0:0:0/scsi_device/0:0:0:0 (scsi_device)
UDEV  [893.262439] add      /devices/platform/soc/3f980000.usb/usb1/1-1/1-1.2/1-1.2:1.4/host1/target1:0:0/1:0:0:0/bsg/1:0:0:0 (bsg)
UDEV  [893.264472] add      /devices/platform/soc/3f980000.usb/usb1/1-1/1-1.2/1-1.2:1.4/host1/target1:0:0/1:0:0:0/scsi_generic/sg1 (scsi_generic)
UDEV  [893.265433] add      /devices/platform/soc/3f980000.usb/usb1/1-1/1-1.2/1-1.2:1.3/host0/target0:0:0/0:0:0:0/bsg/0:0:0:0 (bsg)
UDEV  [893.268924] add      /devices/platform/soc/3f980000.usb/usb1/1-1/1-1.2/1-1.2:1.3/host0/target0:0:0/0:0:0:0/scsi_generic/sg0 (scsi_generic)
UDEV  [893.271819] add      /devices/platform/soc/3f980000.usb/usb1/1-1/1-1.2/1-1.2:1.4/host1/target1:0:0/1:0:0:0/block/sda (block)
UDEV  [893.280708] change   /devices/platform/soc/3f980000.usb/usb1/1-1/1-1.2/1-1.2:1.4/host1/target1:0:0/1:0:0:0/block/sda (block)
UDEV  [893.650868] add      /devices/platform/soc/3f980000.usb/usb1/1-1/1-1.2/1-1.2:1.3/host0/target0:0:0/0:0:0:0/block/sr0 (block)
UDEV  [893.748424] change   /devices/platform/soc/3f980000.usb/usb1/1-1/1-1.2/1-1.2:1.3/host0/target0:0:0/0:0:0:0/block/sr0 (block)

jonnor@display0:~ $ udevadm info -a --name /dev/ttyUSB0

Udevadm info starts with the device specified by the devpath and then
walks up the chain of parent devices. It prints for every device
found, all possible attributes in the udev rules key format.
A rule to match, can be composed by the attributes of the device
and the attributes from one single parent device.

  looking at device '/devices/platform/soc/3f980000.usb/usb1/1-1/1-1.2/1-1.2:1.0/ttyUSB0/tty/ttyUSB0':
    KERNEL=="ttyUSB0"
    SUBSYSTEM=="tty"
    DRIVER==""

  looking at parent device '/devices/platform/soc/3f980000.usb/usb1/1-1/1-1.2/1-1.2:1.0/ttyUSB0':
    KERNELS=="ttyUSB0"
    SUBSYSTEMS=="usb-serial"
    DRIVERS=="option1"
    ATTRS{port_number}=="0"

  looking at parent device '/devices/platform/soc/3f980000.usb/usb1/1-1/1-1.2/1-1.2:1.0':
    KERNELS=="1-1.2:1.0"
    SUBSYSTEMS=="usb"
    DRIVERS=="option"
    ATTRS{authorized}=="1"
    ATTRS{bAlternateSetting}==" 0"
    ATTRS{bInterfaceClass}=="ff"
    ATTRS{bInterfaceNumber}=="00"
    ATTRS{bInterfaceProtocol}=="12"
    ATTRS{bInterfaceSubClass}=="02"
    ATTRS{bNumEndpoints}=="02"
    ATTRS{supports_autosuspend}=="1"

  looking at parent device '/devices/platform/soc/3f980000.usb/usb1/1-1/1-1.2':
    KERNELS=="1-1.2"
    SUBSYSTEMS=="usb"
    DRIVERS=="usb"
    ATTRS{authorized}=="1"
    ATTRS{avoid_reset_quirk}=="1"
    ATTRS{bConfigurationValue}=="1"
    ATTRS{bDeviceClass}=="00"
    ATTRS{bDeviceProtocol}=="00"
    ATTRS{bDeviceSubClass}=="00"
    ATTRS{bMaxPacketSize0}=="64"
    ATTRS{bMaxPower}=="2mA"
    ATTRS{bNumConfigurations}=="1"
    ATTRS{bNumInterfaces}==" 5"
    ATTRS{bcdDevice}=="0102"
    ATTRS{bmAttributes}=="80"
    ATTRS{busnum}=="1"
    ATTRS{configuration}==""
    ATTRS{devnum}=="7"
    ATTRS{devpath}=="1.2"
    ATTRS{devspec}=="  (null)"
    ATTRS{idProduct}=="1506"
    ATTRS{idVendor}=="12d1"
    ATTRS{ltm_capable}=="no"
    ATTRS{manufacturer}=="HUAWEI_MOBILE"
    ATTRS{maxchild}=="0"
    ATTRS{product}=="HUAWEI_MOBILE"
    ATTRS{quirks}=="0x10"
    ATTRS{removable}=="removable"
    ATTRS{speed}=="480"
    ATTRS{urbnum}=="2056"
    ATTRS{version}==" 2.10"

  looking at parent device '/devices/platform/soc/3f980000.usb/usb1/1-1':
    KERNELS=="1-1"
    SUBSYSTEMS=="usb"
    DRIVERS=="usb"
    ATTRS{authorized}=="1"
    ATTRS{avoid_reset_quirk}=="0"
    ATTRS{bConfigurationValue}=="1"
    ATTRS{bDeviceClass}=="09"
    ATTRS{bDeviceProtocol}=="02"
    ATTRS{bDeviceSubClass}=="00"
    ATTRS{bMaxPacketSize0}=="64"
    ATTRS{bMaxPower}=="2mA"
    ATTRS{bNumConfigurations}=="1"
    ATTRS{bNumInterfaces}==" 1"
    ATTRS{bcdDevice}=="0bb3"
    ATTRS{bmAttributes}=="e0"
    ATTRS{busnum}=="1"
    ATTRS{configuration}==""
    ATTRS{devnum}=="2"
    ATTRS{devpath}=="1"
    ATTRS{idProduct}=="2514"
    ATTRS{idVendor}=="0424"
    ATTRS{ltm_capable}=="no"
    ATTRS{maxchild}=="4"
    ATTRS{quirks}=="0x0"
    ATTRS{removable}=="unknown"
    ATTRS{speed}=="480"
    ATTRS{urbnum}=="85"
    ATTRS{version}==" 2.00"

  looking at parent device '/devices/platform/soc/3f980000.usb/usb1':
    KERNELS=="usb1"
    SUBSYSTEMS=="usb"
    DRIVERS=="usb"
    ATTRS{authorized}=="1"
    ATTRS{authorized_default}=="1"
    ATTRS{avoid_reset_quirk}=="0"
    ATTRS{bConfigurationValue}=="1"
    ATTRS{bDeviceClass}=="09"
    ATTRS{bDeviceProtocol}=="01"
    ATTRS{bDeviceSubClass}=="00"
    ATTRS{bMaxPacketSize0}=="64"
    ATTRS{bMaxPower}=="0mA"
    ATTRS{bNumConfigurations}=="1"
    ATTRS{bNumInterfaces}==" 1"
    ATTRS{bcdDevice}=="0414"
    ATTRS{bmAttributes}=="e0"
    ATTRS{busnum}=="1"
    ATTRS{configuration}==""
    ATTRS{devnum}=="1"
    ATTRS{devpath}=="0"
    ATTRS{idProduct}=="0002"
    ATTRS{idVendor}=="1d6b"
    ATTRS{interface_authorized_default}=="1"
    ATTRS{ltm_capable}=="no"
    ATTRS{manufacturer}=="Linux 4.14.71-v7+ dwc_otg_hcd"
    ATTRS{maxchild}=="1"
    ATTRS{product}=="DWC OTG Controller"
    ATTRS{quirks}=="0x0"
    ATTRS{removable}=="unknown"
    ATTRS{serial}=="3f980000.usb"
    ATTRS{speed}=="480"
    ATTRS{urbnum}=="31"
    ATTRS{version}==" 2.00"

  looking at parent device '/devices/platform/soc/3f980000.usb':
    KERNELS=="3f980000.usb"
    SUBSYSTEMS=="platform"
    DRIVERS=="dwc_otg"
    ATTRS{busconnected}=="Bus Connected = 0x1"
    ATTRS{buspower}=="Bus Power = 0x1"
    ATTRS{bussuspend}=="Bus Suspend = 0x0"
    ATTRS{devspeed}=="Device Speed = 0x0"
    ATTRS{driver_override}=="(null)"
    ATTRS{enumspeed}=="Device Enumeration Speed = 0x1"
    ATTRS{fr_interval}=="Frame Interval = 0x1d4b"
    ATTRS{ggpio}=="GGPIO = 0x00000000"
    ATTRS{gnptxfsiz}=="GNPTXFSIZ = 0x01000306"
    ATTRS{gotgctl}=="GOTGCTL = 0x001c0000"
    ATTRS{gpvndctl}=="GPVNDCTL = 0x00000000"
    ATTRS{grxfsiz}=="GRXFSIZ = 0x00000306"
    ATTRS{gsnpsid}=="GSNPSID = 0x4f54280a"
    ATTRS{guid}=="GUID = 0x2708a000"
    ATTRS{gusbcfg}=="GUSBCFG = 0x20001700"
    ATTRS{hcd_frrem}=="HCD Dump Frame Remaining"
    ATTRS{hcddump}=="HCD Dump"
    ATTRS{hnp}=="HstNegScs = 0x0"
    ATTRS{hnpcapable}=="HNPCapable = 0x1"
    ATTRS{hprt0}=="HPRT0 = 0x00001005"
    ATTRS{hptxfsiz}=="HPTXFSIZ = 0x02000406"
    ATTRS{hsic_connect}=="HSIC Connect = 0x1"
    ATTRS{inv_sel_hsic}=="Invert Select HSIC = 0x0"
    ATTRS{mode}=="Mode = 0x1"
    ATTRS{mode_ch_tim_en}=="Mode Change Ready Timer Enable = 0x0"
    ATTRS{rd_reg_test}=="Time to read GNPTXFSIZ reg 10000000 times: 1720 msecs (172 jiffies)"
    ATTRS{regdump}=="Register Dump"
    ATTRS{regoffset}=="0xffffffff"
    ATTRS{regvalue}=="invalid offset"
    ATTRS{rem_wakeup_pwrdn}==""
    ATTRS{remote_wakeup}=="Remote Wakeup Sig = 0 Enabled = 0 LPM Remote Wakeup = 0"
    ATTRS{spramdump}=="SPRAM Dump"
    ATTRS{srp}=="SesReqScs = 0x0"
    ATTRS{srpcapable}=="SRPCapable = 0x1"
    ATTRS{wr_reg_test}=="Time to write GNPTXFSIZ reg 10000000 times: 310 msecs (31 jiffies)"

  looking at parent device '/devices/platform/soc':
    KERNELS=="soc"
    SUBSYSTEMS=="platform"
    DRIVERS==""
    ATTRS{driver_override}=="(null)"

  looking at parent device '/devices/platform':
    KERNELS=="platform"
    SUBSYSTEMS==""
    DRIVERS==""

jonnor@display0:~ $ ls -la /lib/udev/rules.d/*mm-*
-rw-r--r-- 1 root root   484 Nov 16  2016 /lib/udev/rules.d/77-mm-cinterion-port-types.rules
-rw-r--r-- 1 root root   646 Nov 16  2016 /lib/udev/rules.d/77-mm-dell-port-types.rules
-rw-r--r-- 1 root root  6910 Nov 16  2016 /lib/udev/rules.d/77-mm-ericsson-mbm.rules
-rw-r--r-- 1 root root   577 Nov 16  2016 /lib/udev/rules.d/77-mm-haier-port-types.rules
-rw-r--r-- 1 root root  1734 Nov 16  2016 /lib/udev/rules.d/77-mm-huawei-net-port-types.rules
-rw-r--r-- 1 root root 13187 Nov 16  2016 /lib/udev/rules.d/77-mm-longcheer-port-types.rules
-rw-r--r-- 1 root root  2869 Nov 16  2016 /lib/udev/rules.d/77-mm-mtk-port-types.rules
-rw-r--r-- 1 root root  2024 Nov 16  2016 /lib/udev/rules.d/77-mm-nokia-port-types.rules
-rw-r--r-- 1 root root   383 Nov 16  2016 /lib/udev/rules.d/77-mm-pcmcia-device-blacklist.rules
-rw-r--r-- 1 root root   514 Nov 16  2016 /lib/udev/rules.d/77-mm-platform-serial-whitelist.rules
-rw-r--r-- 1 root root  3155 Nov 16  2016 /lib/udev/rules.d/77-mm-qdl-device-blacklist.rules
-rw-r--r-- 1 root root  1840 Nov 16  2016 /lib/udev/rules.d/77-mm-simtech-port-types.rules
-rw-r--r-- 1 root root  3268 Nov 16  2016 /lib/udev/rules.d/77-mm-telit-port-types.rules
-rw-r--r-- 1 root root  7245 Nov 16  2016 /lib/udev/rules.d/77-mm-usb-device-blacklist.rules
-rw-r--r-- 1 root root  2452 Nov 16  2016 /lib/udev/rules.d/77-mm-usb-serial-adapters-greylist.rules
-rw-r--r-- 1 root root  3666 Nov 16  2016 /lib/udev/rules.d/77-mm-x22x-port-types.rules
-rw-r--r-- 1 root root 14350 Nov 16  2016 /lib/udev/rules.d/77-mm-zte-port-types.rules
-rw-r--r-- 1 root root   972 Nov 16  2016 /lib/udev/rules.d/80-mm-candidate.rules

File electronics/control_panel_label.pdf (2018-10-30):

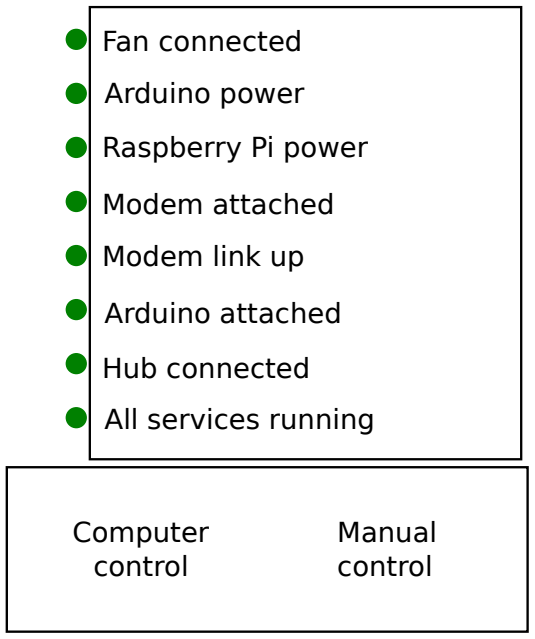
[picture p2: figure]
Raspberry Pi power; Arduino power; Arduino attached; All services running; Modem attached; Modem link up; Hub connected; Fan connected; Manual control; Computer control

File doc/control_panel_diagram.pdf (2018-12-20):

# Wind portal control panel

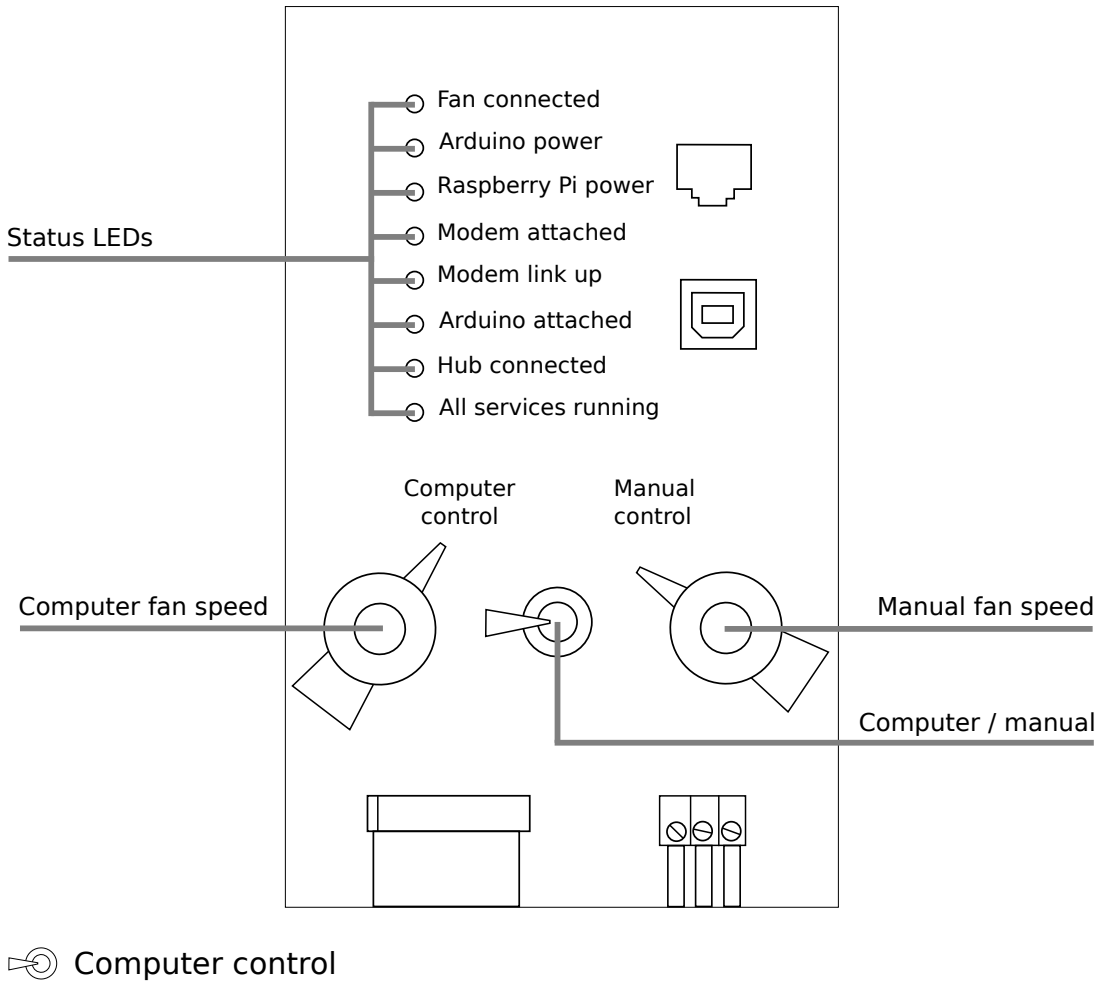
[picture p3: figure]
Computer control; Raspberry Pi power; Arduino power; Arduino attached; All services running; Modem attached; Modem link up; Hub connected; Fan connected; Manual control; Computer fan speed; Manual fan speed; Status LEDs; Computer / manual
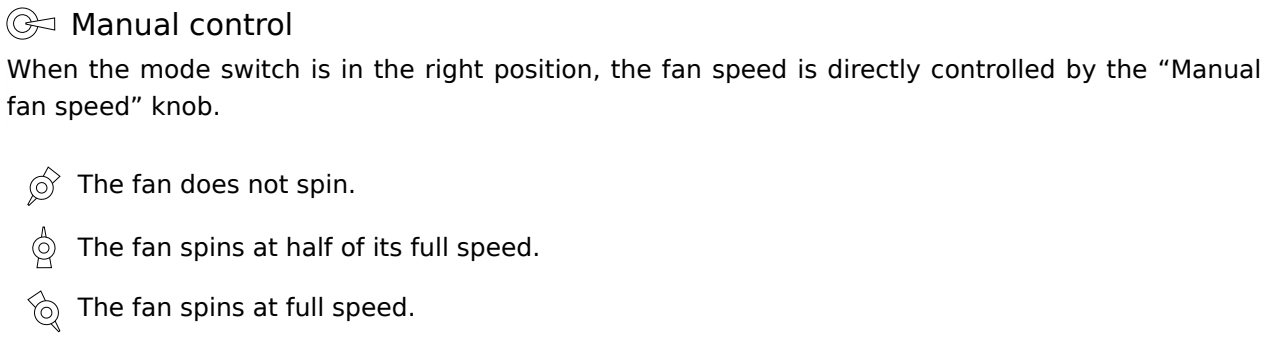
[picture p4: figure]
Manual control; The fan does not spin.; The fan spins at full speed.; fan speed” knob.

The fan spins at half of its full speed.

When the mode switch is in the right position, the fan speed is directly controlled by the “Manual

When the mode switch is in the left position, the fan speed is controlled by computer. In the wind portal's initial soft mode, the fan is set to blow at a constant, low speed. When the front button is pressed, the active mode is entered for 15 seconds. In this mode the screen displays the current wind speed as reported on https://ukenergy.equinor.com/wind. The “Computer fan speed” knob controls the fan speed in the active mode.

0% intensity: When active, the fan spins at the same speed as in the soft mode.

50% intensity: When active, a real wind speed of 8 m/s will run the fan at 50% speed.

100% intensity: When active, a real wind speed of 8 m/s will run the fan at 100% speed.

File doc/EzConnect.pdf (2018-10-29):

## Pi-EzConnect

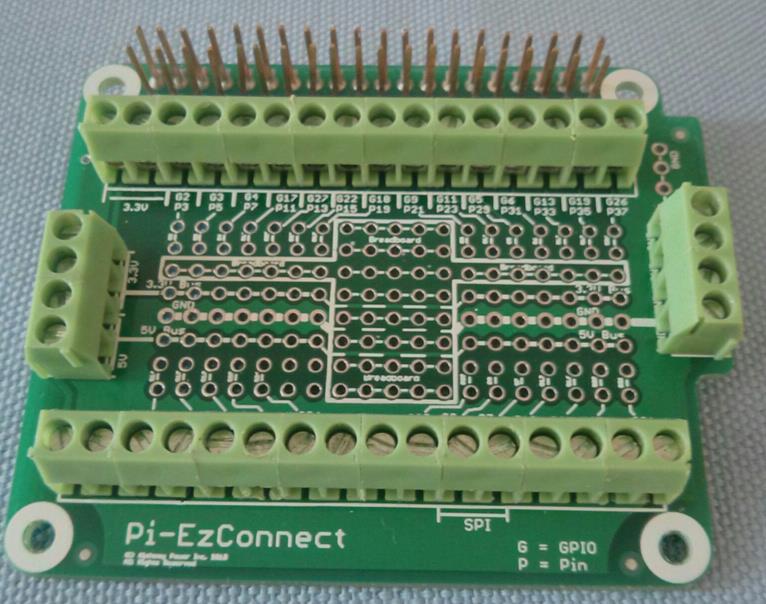
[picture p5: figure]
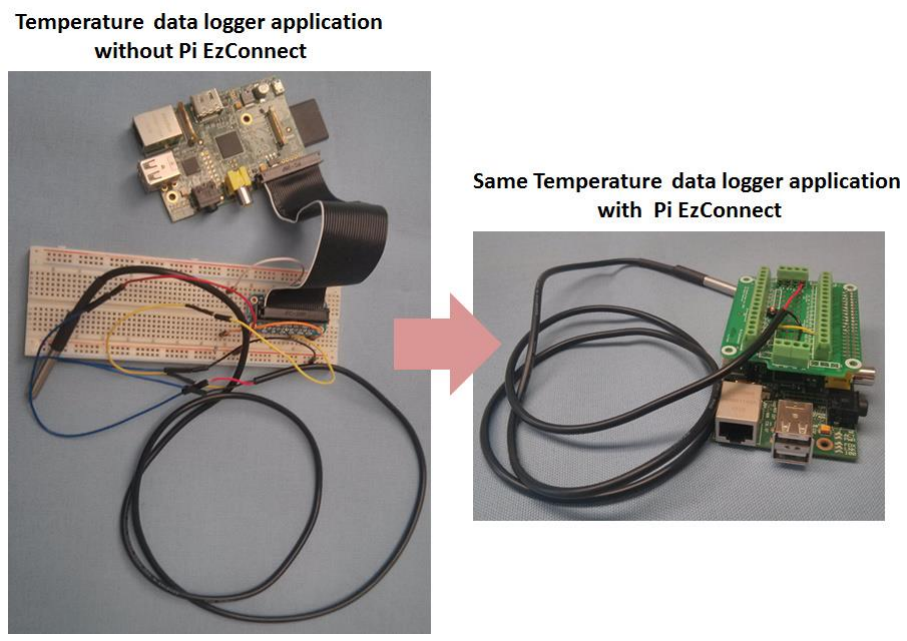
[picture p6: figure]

© 2016 Alchemy Power Inc. All Rights Reserved. 09-16
All information subject to change without notice.

# Pi-EzConnect

Pi-EzConnect makes it
possible to connect
multiple sensors (and
other electronic devices
/ components) to
multiple GPIOs on a
Raspberry Pi. With Pi-EzConnect, you are no
longer limited in the use
of a Raspberry Pi.
Leverage all the GPIO
pins on the Raspberry
Pi. Whether the
Raspberry Pi is used as
a data logger, a drone,
a robot, for video
surveillance or anything
else, you need to connect sensors as well as other electronic components such as pull up or pull down resistors, LED’s etc. These sensors are then managed by the Raspberry Pi. Pi-EzConnect stacks on top of a Raspberry Pi making it possible to add multiple sensors to the Raspberry Pi in the same foot print as the Raspberry Pi. Further, these sensors are securely connected using terminal blocks.

Pi-EzConnect
simplifies
the addition
of sensors.
An example
of adding a
temperature
probe is
shown.

### Key Features

- Allows multiple
digital sensors
(GPIO) to be
connected to a
single Raspberry Pi
– leveraging the
full power of the
Raspberry Pi
- Solderless or
soldered
connections for all
GPIO’s on a
Raspberry Pi
- Mini
breadboard for
adding
components
- Add standard
male or female
headers for
breadboard like
functionality
- Power (both 5V
and 3.3V) as well
as ground
connections
available
- Fuses protect
5V bus as well as
3.3 V bus
- Compact
footprint – fits
easily on top of a
Raspberry Pi
- Fully
documented pins –
easily connect to
pin numbers or
GPIO number
without referring
to external charts

Before Pi-EzConnect, a flat ribbon cable, a breadboard and other wires are being used to connect the temperature sensor to the Raspberry Pi. With the Pi-EzConnect, the connection is simplified as shown.

Watch the video on You Tube -
https://youtu.be/oChXSE0etQw

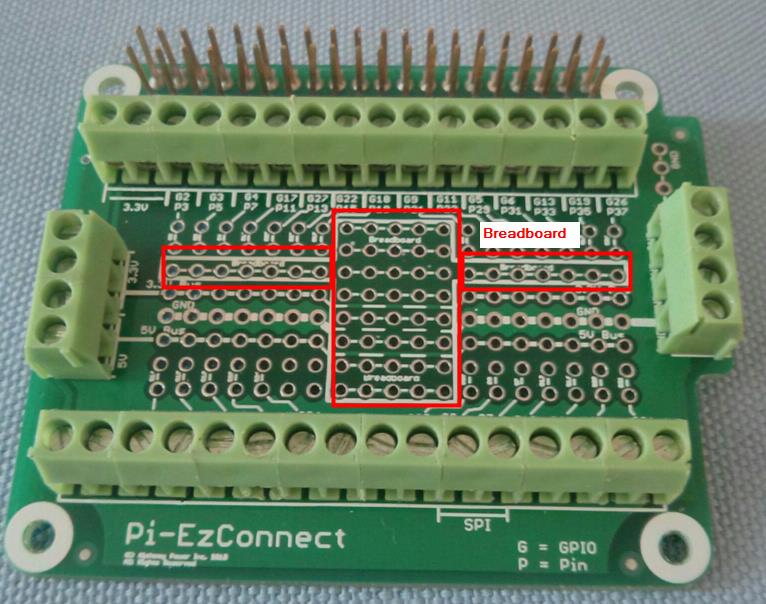
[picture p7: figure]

Picture on the right shows the breadboard area of Pi-EzConnect board.

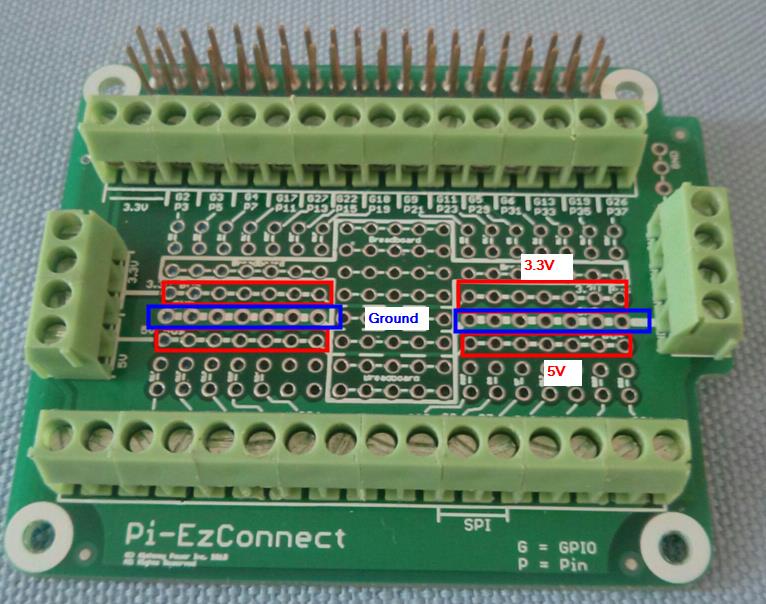
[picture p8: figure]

Power bus – both 3.3V as
well as the 5V power bus
is available on Pi-EzConnect. Ground bus is
also available (shown in
blue) on Pi-EzConnect.

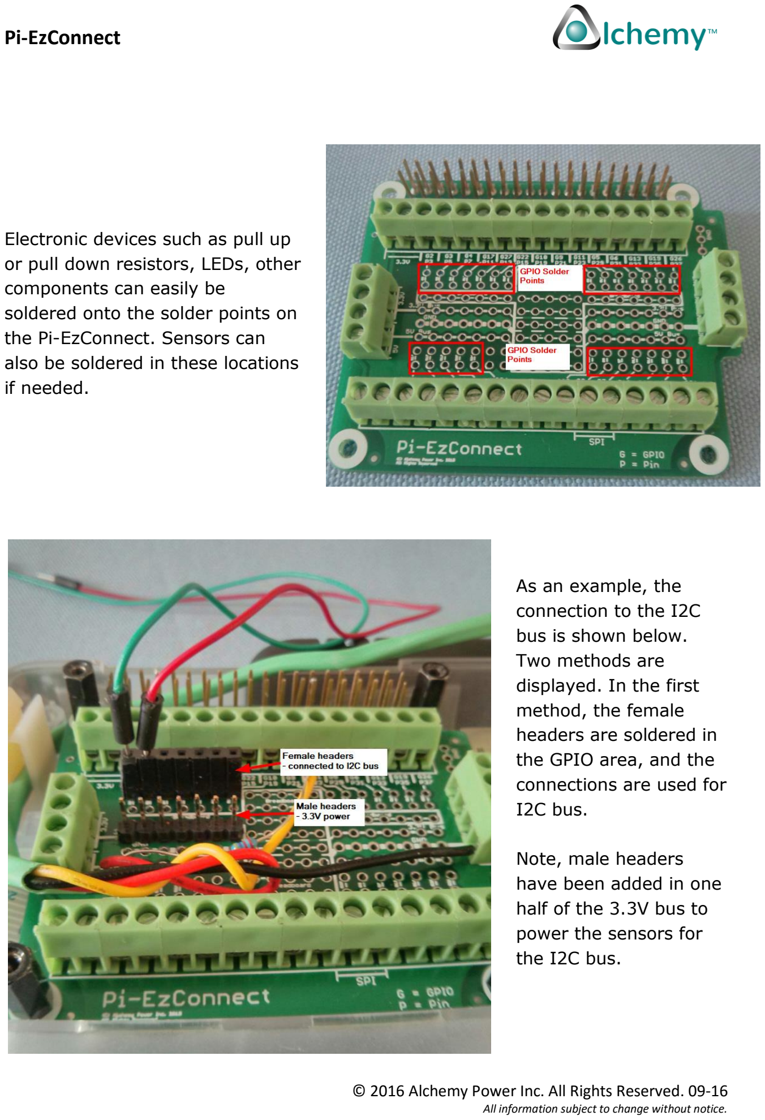
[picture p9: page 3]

Electronic devices such as pull up or pull down resistors, LEDs, other components can easily be
soldered onto the solder points on the Pi-EzConnect. Sensors can also be soldered in these locations if needed.

As an example, the
connection to the I2C
bus is shown below.
Two methods are
displayed. In the first
method, the female
headers are soldered in
the GPIO area, and the
connections are used for
I2C bus.

Note, male headers
have been added in one
half of the 3.3V bus to
power the sensors for
the I2C bus.

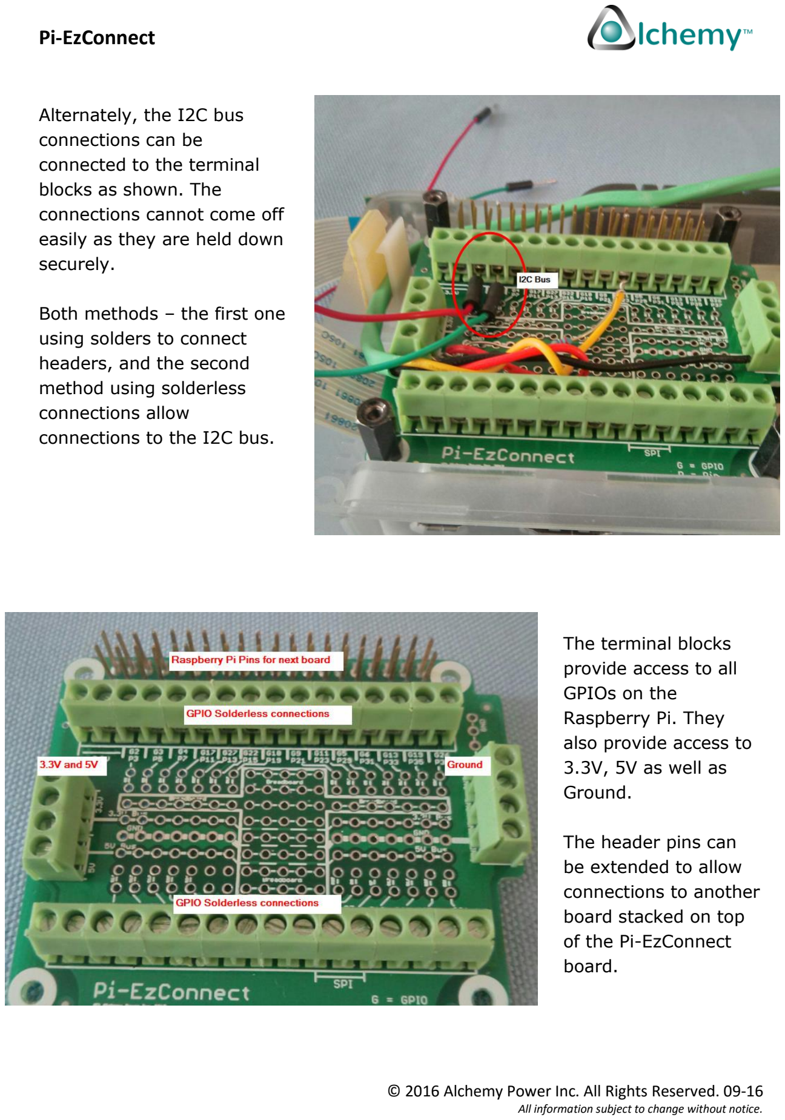
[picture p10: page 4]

Alternately, the I2C bus
connections can be
connected to the terminal
blocks as shown. The
connections cannot come off easily as they are held down securely.

Both methods – the first one using solders to connect
headers, and the second
method using solderless
connections allow
connections to the I2C bus.

The terminal blocks
provide access to all
GPIOs on the
Raspberry Pi. They
also provide access to
3.3V, 5V as well as
Ground.

The header pins can
be extended to allow
connections to another
board stacked on top
of the Pi-EzConnect
board.

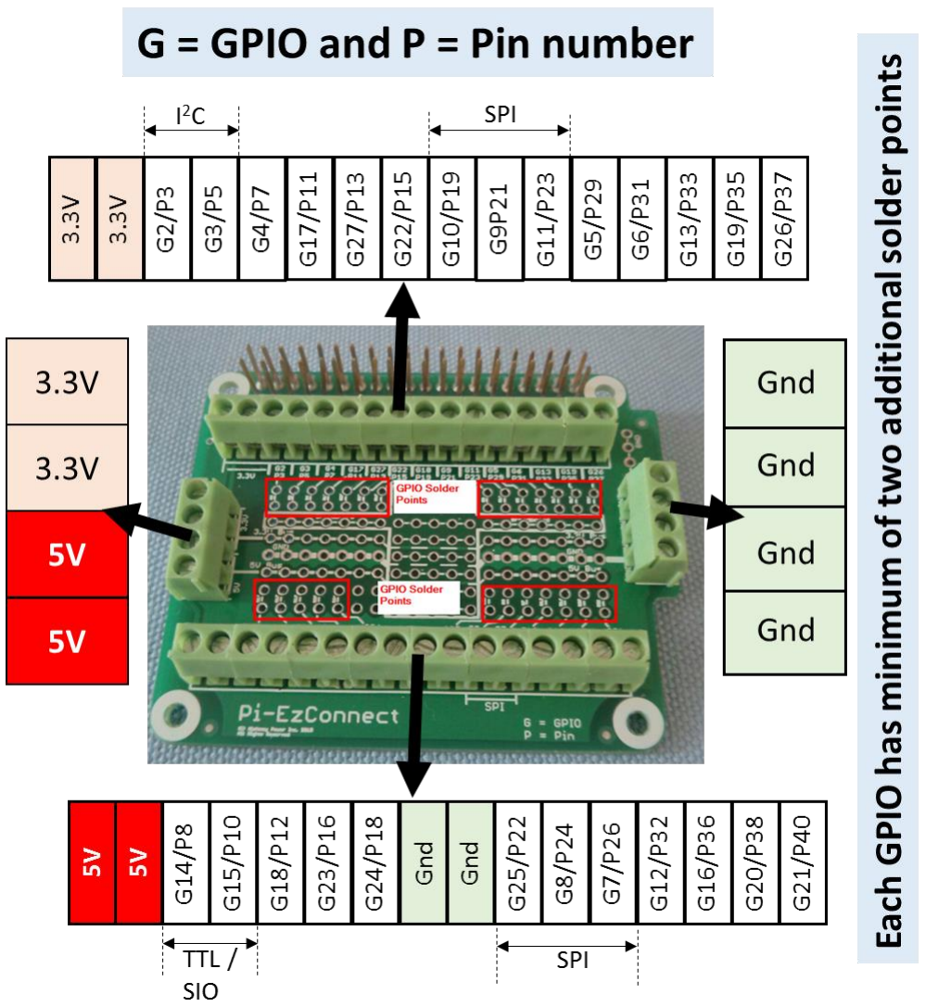
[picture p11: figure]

Pin out configuration details for Pi-EzConnect. The GPIO solder points are also shown in the picture.

© 2016 Alchemy Power Inc. All Rights Reserved.

### Specifications

General Information
Model Number: Pi-EzConnect.
Protection: resettable 8V, 1.6A fuse. Protects 3.3V and 5V power.
GPIO and pin connections: Displayed on the board. G followed by number corresponds to GPIO number. P followed by number corresponds to pin number. For example G3, P5 corresponds to GIPO 5, Pin 3. Header connections: 0.1” or 2.54 mm spaced headers, male or female.
Standoff connections: Matches Raspberry Pi model A+, B+, Pi 2 and Pi 3. Recommend brass standoff’s for Raspberry Pi.
Other information: A minimum of 2 solder points for each Raspberry Pi header pin or GPIO (except those pins which are reserved by Raspberry Pi foundation).
Breadboard: Ten (10) connection strings for breadboard – each string has seven (7) connection points.
Dimension/Weight:
Board Dimensions: 69mmx56mm.
Board thickness: 1.5mm.
Terminal Blocks: 9mm from base of the board. Weight: 32 grams (appx 1.2 ounces)
Raspberry Pi connector header dimensions: Female pins – 11mm, male pins 12mm (note – board thickness is appx 2 mm – so only 10mm of the pins are accessible.)
Safety:
Passive board. Power ports connect to power pins on the Raspberry Pi.
Warranty:
90 days parts and labor limited warranty.

Recommended Accessories:
Most accessories can be purchased from several web sites or online stores. Adafruit™ web site (www.adafruit.com) accessories are listed as a reference only.

Standoff – example, Adafruit Product ID 2336 or 2337
Headers – example, Adafruit Product ID 85 – 0.1” or 2.54 mm spaced male or female headers.

Please follow recommended safety regulations when soldering or using electronic components or making connections or connecting power supplies to Raspberry Pi.

™ Adafruit is a registered trademark of Adafruit Industries, LLC.

Alchemy Power Inc.

2098 Walsh Avenue, Suite A, Santa Clara, CA 95050-2544 Phone: 650.823.2316
Email: sales@alchemypower.com www.alchemy-power.com

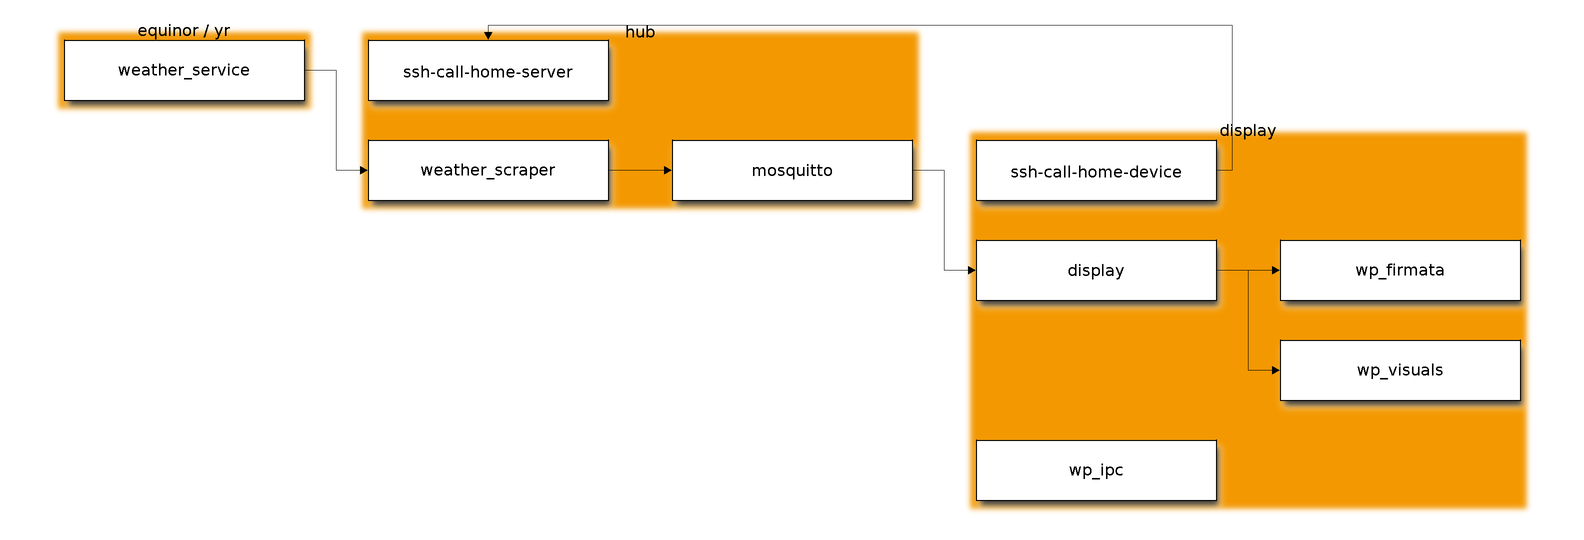
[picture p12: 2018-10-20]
doc/diagrams/software.png

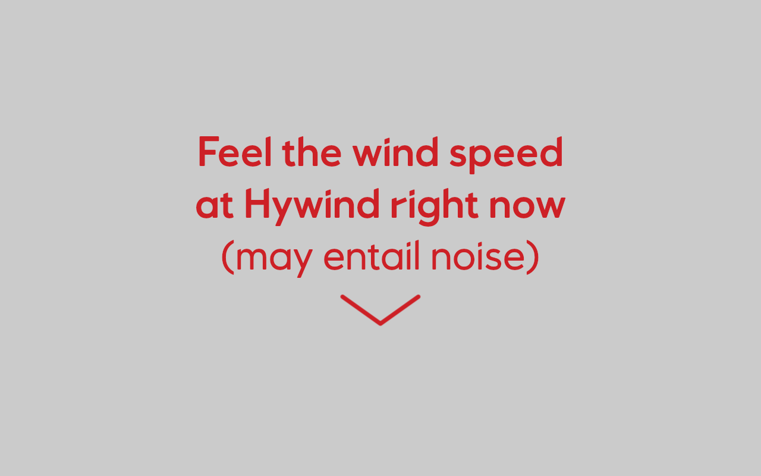
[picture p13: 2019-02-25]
firmware/wp_visuals/idle.png

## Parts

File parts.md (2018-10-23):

power supply
------------

5V 4A + 12V 1A                      250 kr
https://www.kjell.com/no/produkter/elektro-og-verktoy/stromforsyning/stromforsyning/ac-dc/fast-utgangsspenning/mean-well-switchet-stromaggregat-5-12-v-(dc)-32-w-p442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

sukkerbit                           100 kr
https://www.kjell.com/no/produkter/elektro-og-verktoy/elektrisk-installasjon/kobling-bokser-lister/wago-221-412-toppklemme-med-2-tilkoblinger-16-pk--p36900

koblingsboks                        120 kr
https://www.clasohlson.com/no/Koblingsboks/Pr327387000

servo-motor for å styre spjeld
------------------------------

elefun er i grimstad.

Dragon-RC Servo Digital MG 10.5kg/0.19s
https://www.elefun.no/p/prod.aspx?v=31447
425 kr

Pilot-RC PW-38AH Brushless Digital Servo
https://www.elefun.no/p/prod.aspx?v=39230
Styrke  34kg ved 7,4V / 38kg ved 8,4V
1020 kr

LS-8101F                    13 kg cm
https://no.mouser.com/ProductDetail/OSEPP-Electronics/LS-8101F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

control panel
-------------

Miniatyrbryter 2-polet, til-fra-til     45 kr
https://www.kjell.com/no/produkter/elektro-og-verktoy/elektronikk/electromechanics/strombrytere/vippebrytere/miniatyrbryter-2-polet-til-fra-til-p36022

skjerm
------

HA-101ZIEB0HH1-A            10"     2000 kr
https://no.mouser.com/ProductDetail/Microtips-Technology/HA-101ZIEB0HH1-A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

Power supply, 12 V, 1 A             140 kr
https://www.kjell.com/no/produkter/elektro-og-verktoy/stromforsyning/stromforsyning/ac-dc/fast-utgangsspenning/switchet-stromadapter-12-v-(dc)-12-w-p44382

skjermkabel
-----------

hdmi 2 meter                        140 kr
https://no.mouser.com/ProductDetail/Molex/88768-9810?qs=sGAEpiMZZMtQmYd0M89TfUhPvdkn5Y6bpxE9MPLzmCE%3d

arduino
-------

leonardo                            190 kr      **backordered**
https://no.mouser.com/ProductDetail/DFRobot/DFR0201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

skruterminaler                      130 kr
https://no.mouser.com/ProductDetail/Adafruit/196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

rpi
---

model 3b+                           440 kr
https://no.mouser.com/ProductDetail/Raspberry-Pi/RPI3-MODBP-BULK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

sd industrial 8 GB                  100 kr
https://no.mouser.com/ProductDetail/SanDisk/SDSDQAF3-008G-XI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

power supply                        100 kr
https://no.mouser.com/ProductDetail/Raspberry-Pi/1101001000045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

motstand (led)              270     14 kr / 100 stk
https://no.mouser.com/ProductDetail/Yageo/CFR-25JT-52-270R?qs=sGAEpiMZZMtlubZbdhIBIFoOGUvNp40aQpaHJWY8dGI%3d

motstand (led)              390     14 kr / 100 stk
https://no.mouser.com/ProductDetail/Yageo/CFR-25JT-52-390R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

motstand (knapp)            4.7k    10 kr / 100 stk
https://no.mouser.com/ProductDetail/Yageo/CFR-25JT-52-4K7?qs=sGAEpiMZZMtlubZbdhIBIGhJWRsHPi3SRC60A9RSQDI%3d

skruterminaler
https://no.mouser.com/ProductDetail/Adafruit/2711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

rs485
-----

USB-COM485-PLUS1            220 kr
https://no.mouser.com/ProductDetail/FTDI/USB-COM485-PLUS1?qs=sGAEpiMZZMt1Kg3wsyvxe%252bLLaQGiBr1h

PWM to analog
---
Optically isolated      **out of stock**
https://www.banggood.com/PWM-To-Voltage-Conversion-Module-0-100-PWM-To-0-10V-Voltage-p-1223296.html?

Aptinex DAC Module DA1C010BI I2C Digital to Analog 0-10V MCP4725    $30
https://aptinex.com/product/aptinex-dac-module-da1c010bi-digital-to-analog-0-10v-mcp4725-i2c/

https://www.duino.lt/duino/14450-arduino-pwm-signalo-keitiklis-i-0-51024v.html

3/4G modem
---

Huawei E3372
https://consumer.huawei.com/en/mobile-broadband/e3372/specs/ says
Popular USB with external antenna support
https://prisguiden.no/produkt/huawei-e3372-246441
Available locally in Oslo
https://www.teknikmagasinet.no/produkter/gaming-data/nettverk/4g-routere/huawei-e3372h-153-4g-usb-modem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

Connector:  CRC-9, aka TS-5
x2, for MIMO antenna

Overgang til SMA
https://www.kjell.com/no/produkter/data-og-nettverk/nettverk/mobilt-bredband/adapter/antenneadapter-sma-til-crc-9-p30854

Industrial module, USB interface
https://www.digikey.com/product-detail/en/sierra-wireless/GL8200-INT_1102574/1645-1010-ND/5843807

Serial modules. Theoretically works with PPP
https://www.digikey.com/products/en/development-boards-kits-programmers/evaluation-boards-expansion-boards-daughter-cards/797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

# Components

## Brainz
Control:
Fan(s) 1-2

+ Firmata on Arduino for GPIO extender

Raspberry PI
5V power supply
SD card
Enclosure
Arduino Leonardo: IO extender

1500 NOK

## Connectivity
USB modem 3g

modem. 500 NOK
SIM for test. 200 

1000 NOK

## Control panel
3x buttons
3x LEDs

## Fan control
Analog 0-10V or

Modbus?
https://github.com/riptideio/pymodbus
https://pypi.org/project/MinimalModbus/
RS-485 or RS-232
USB adapter?

500 NOK

## Valve control
Servo or stepper(+encoder/endstop)

Speed needed: 0.5 sec/90 grad

Torque needed?
GUESS: 10kg/cm, 1Nm ++

Servo motors AC
https://www.digikey.com/products/en/motors-solenoids-driver-boards-modules/motors-ac-dc/178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

DC servo motor
Up to 6Nm. HobbyKing
1Nm https://www.digikey.com/product-detail/en/adafruit-industries-llc/1142/1528-1083-ND/5154658

Nema23, 10-20 kg/cm

Absolute encoder, SPI
https://www.digikey.com/product-detail/en/cui-inc/AMT203-V/102-2050-ND/2278846

Budsjett:
Motors (incl drivers) 2x 1500kr
500 NOK

3500 NOK

### LCD high brightness
https://blog.peerless-av.com/digital-signage-basics-nits-brightness-led-vs-lcd-displays/
Common brightness requirements are 800 to 1,500 nits for indoor displays,
and 1,500 to 2,500 nits for indoor displays in direct sunlight.

For outdoors, on the other hand, up to 5,000 nits is generally recommended
and for those in direct sunlight, 5,000+ nits is recommended.

LCD panel, 10", 1000 nits
TOOD: link
3k NOK 

10k NOK
https://prisguiden.no/produkt/philips-signage-solutions-p-line-42bdl5057p-340915#detaljer
https://prisguiden.no/kategorier/pc-skjerm?f[90][]=Minst%20600%20cd%2Fm2&f[90][]=Minst%201000%20cd%2Fm2&s=price%20asc

### Analog gauge.
Servo + vinyl
1000k

7-segment
150mm, red, needs custom driver
https://www.sparkfun.com/products/8530
https://www.digikey.com/products/en/optoelectronics/display-modules-led-character-and-numeric/92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

LED dot matrix (flippers)
5k

## Status
Power,booted,modem,SSH-call-home,servercomm,graphicservice,controlservice
8 LEDS

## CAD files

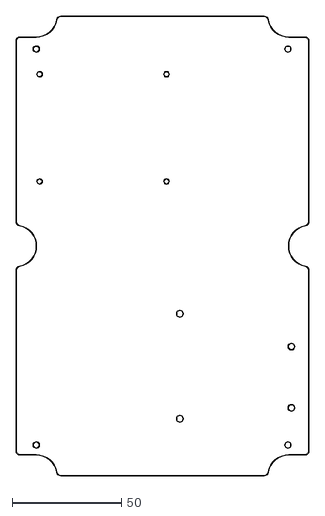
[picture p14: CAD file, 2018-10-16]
electronics/baseboard-1.dxf
133.8 x 210.0

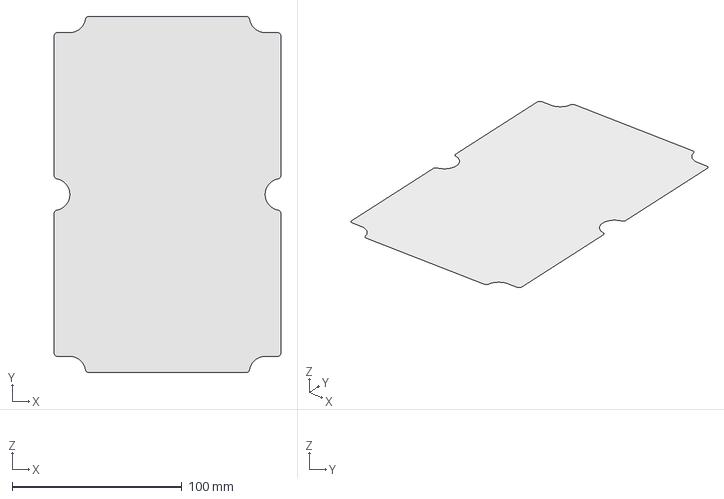
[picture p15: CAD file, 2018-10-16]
electronics/baseboard.fcstd
133.8 x 210.0 x 0 mm

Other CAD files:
electronics/psu.fcstd
electronics/psu.dxf

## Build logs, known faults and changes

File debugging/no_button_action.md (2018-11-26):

--------------------------------  2018-11-26  --------------------------------

2018-11-26 13:20:59 +0100	hos gpj

```
mastensg@display0:~ $ journalctl -u display-firmata -n 1000 -f
-- Logs begin at Thu 2016-11-03 17:16:43 UTC. --
Nov 20 12:17:05 display0 systemd[1]: Started display-firmata.service.
-- Reboot --
Nov 26 12:00:16 display0 systemd[1]: Started display-firmata.service.
-- Reboot --
Nov 26 12:05:06 display0 systemd[1]: Started display-firmata.service.
-- Reboot --
Nov 26 12:07:26 display0 systemd[1]: Started display-firmata.service.
Nov 26 12:08:53 display0 python[318]: Python Version 3.5.3 (default, Sep 27 2018, 17:25:39)
Nov 26 12:08:53 display0 python[318]: [GCC 6.3.0 20170516]
Nov 26 12:08:53 display0 python[318]: PyMata version 2.18  Copyright(C) 2013-18 Alan Yorinks    All rights reserved.
Nov 26 12:08:53 display0 python[318]: Opening Arduino Serial port /dev/ttyACM0
Nov 26 12:08:53 display0 python[318]: Please wait while Arduino is being detected. This can take up to 30 seconds ...
Nov 26 12:08:53 display0 python[318]: Board Auto Discovery Failed!, Shutting Down
Nov 26 12:08:53 display0 python[318]: Traceback (most recent call last):
Nov 26 12:08:53 display0 python[318]:   File "/opt/windmachine/firmware/wp_firmata.py", line 56, in <module>
Nov 26 12:08:53 display0 python[318]:     main()
Nov 26 12:08:53 display0 python[318]:   File "/opt/windmachine/firmware/wp_firmata.py", line 23, in main
Nov 26 12:08:53 display0 python[318]:     board.set_pin_mode(LED_PIN, board.OUTPUT, board.DIGITAL)
Nov 26 12:08:53 display0 python[318]:   File "/opt/windmachine/venv/lib/python3.5/site-packages/PyMata/pymata.py", line 802, in set_pin_mode
Nov 26 12:08:53 display0 python[318]:     self._command_handler.send_command(command)
Nov 26 12:08:53 display0 python[318]:   File "/opt/windmachine/venv/lib/python3.5/site-packages/PyMata/pymata_command_handler.py", line 656, in send_command
Nov 26 12:08:53 display0 python[318]:     self.pymata.transport.write(data)
Nov 26 12:08:53 display0 python[318]:   File "/opt/windmachine/venv/lib/python3.5/site-packages/PyMata/pymata_serial.py", line 108, in write
Nov 26 12:08:53 display0 python[318]:     self.arduino.write(bytes([ord(data)]))
Nov 26 12:08:53 display0 python[318]:   File "/opt/windmachine/venv/lib/python3.5/site-packages/serial/serialposix.py", line 531, in write
Nov 26 12:08:53 display0 python[318]:     raise portNotOpenError
Nov 26 12:08:53 display0 python[318]: serial.serialutil.SerialException: Attempting to use a port that is not open
Nov 26 12:08:53 display0 systemd[1]: display-firmata.service: Main process exited, code=exited, status=1/FAILURE
Nov 26 12:08:53 display0 systemd[1]: display-firmata.service: Unit entered failed state.
Nov 26 12:08:53 display0 systemd[1]: display-firmata.service: Failed with result 'exit-code'.
Nov 26 12:09:03 display0 systemd[1]: display-firmata.service: Service hold-off time over, scheduling restart.
Nov 26 12:09:03 display0 systemd[1]: Stopped display-firmata.service.
Nov 26 12:09:03 display0 systemd[1]: Started display-firmata.service.
-- Reboot --
Nov 26 12:10:27 display0 systemd[1]: Started display-firmata.service.
mastensg@display0:~ $ ps aux | grep firmata
display    320  104  1.4  55988 13484 ?        Rsl  12:11  11:28 /opt/windmachine/venv/bin/python /opt/windmachine/firmware/wp_firmata.py
mastensg  1549  0.0  0.0   4372   532 pts/0    S+   12:22   0:00 grep --color=auto firmata
mastensg@display0:~ $ sudo strace -p 320 2>&1 | head -10
strace: Process 320 attached
write(13, "\367", 1)                    = -1 EAGAIN (Resource temporarily unavailable)
write(13, "\367", 1)                    = -1 EAGAIN (Resource temporarily unavailable)
write(13, "\367", 1)                    = -1 EAGAIN (Resource temporarily unavailable)
write(13, "\367", 1)                    = -1 EAGAIN (Resource temporarily unavailable)
write(13, "\367", 1)                    = -1 EAGAIN (Resource temporarily unavailable)
write(13, "\367", 1)                    = -1 EAGAIN (Resource temporarily unavailable)
write(13, "\367", 1)                    = -1 EAGAIN (Resource temporarily unavailable)
write(13, "\367", 1)                    = -1 EAGAIN (Resource temporarily unavailable)
write(13, "\367", 1)                    = -1 EAGAIN (Resource temporarily unavailable)
mastensg@display0:~ $ sudo ls -l /proc/320/fd/13
lrwx------ 1 display display 64 Nov 26 12:10 /proc/320/fd/13 -> /dev/ttyACM0
mastensg@display0:~ $ ps aux | grep -i modem
root       310  0.0  0.8  53020  7804 ?        Ssl  12:11   0:00 /usr/sbin/ModemManager
mastensg  1658  0.0  0.0   4372   556 pts/0    S+   12:25   0:00 grep --color=auto -i modem
mastensg@display0:~ $ sudo ls -l /proc/310/fd
total 0
lr-x------ 1 root root 64 Nov 26 12:10 0 -> /dev/null
lrwx------ 1 root root 64 Nov 26 12:10 1 -> socket:[12313]
lrwx------ 1 root root 64 Nov 26 12:10 10 -> /dev/ttyUSB0
lrwx------ 1 root root 64 Nov 26 12:10 11 -> /dev/ttyUSB1
l-wx------ 1 root root 64 Nov 26 12:10 2 -> /dev/null
lrwx------ 1 root root 64 Nov 26 12:10 3 -> anon_inode:[eventfd]
lrwx------ 1 root root 64 Nov 26 12:10 4 -> anon_inode:[eventfd]
lrwx------ 1 root root 64 Nov 26 12:10 5 -> socket:[12401]
lrwx------ 1 root root 64 Nov 26 12:10 6 -> anon_inode:[eventfd]
lrwx------ 1 root root 64 Nov 26 12:10 7 -> socket:[11604]
lrwx------ 1 root root 64 Nov 26 12:10 8 -> socket:[13396]
l-wx------ 1 root root 64 Nov 26 12:10 9 -> /run/systemd/inhibit/1.ref
mastensg@display0:~ $ ls -l /dev/tty[A-Z]*
crw-rw---- 1 root dialout 166,  0 Nov 26 12:10 /dev/ttyACM0
crw--w---- 1 root tty     204, 64 Nov 26 12:10 /dev/ttyAMA0
crw------- 1 root root      5,  3 Nov 20 12:17 /dev/ttyprintk
crw-rw---- 1 root dialout   4, 64 Nov 20 12:17 /dev/ttyS0
crw-rw---- 1 root dialout 188,  0 Nov 26 12:26 /dev/ttyUSB0
crw-rw---- 1 root dialout 188,  1 Nov 26 12:10 /dev/ttyUSB1
mastensg@display0:~ $
```

## mitigation

* enable watchdog for `display-firmata` service

`WatchdogSec=30`

```
mastensg@display0:~ $ sudo systemctl restart display-firmata
Warning: display-firmata.service changed on disk. Run 'systemctl daemon-reload' to reload units.
mastensg@display0:~ $ sudo systemctl daemon-reload
mastensg@display0:~ $ sudo systemctl restart display-firmata
mastensg@display0:~ $ journalctl -f
-- Logs begin at Thu 2016-11-03 17:16:43 UTC. --
Nov 26 12:49:43 display0 sudo[2659]: pam_unix(sudo:session): session opened for user root by mastensg(uid=0)
Nov 26 12:49:43 display0 systemd[1]: Stopped display-firmata.service.
Nov 26 12:49:43 display0 systemd[1]: Started display-firmata.service.
Nov 26 12:49:44 display0 sudo[2659]: pam_unix(sudo:session): session closed for user root
Nov 26 12:49:44 display0 systemd[1]: Started display-status-led.service.
Nov 26 12:49:45 display0 systemd[1]: display-firmata.service: Watchdog timeout (limit 1s)!
Nov 26 12:49:45 display0 systemd[1]: display-firmata.service: Killing process 2666 (python) with signal SIGABRT.
Nov 26 12:49:45 display0 systemd[1]: display-firmata.service: Main process exited, code=killed, status=6/ABRT
Nov 26 12:49:45 display0 systemd[1]: display-firmata.service: Unit entered failed state.
Nov 26 12:49:45 display0 systemd[1]: display-firmata.service: Failed with result 'watchdog'.

Nov 26 12:49:54 display0 systemd[1]: Starting display-status-led.service...
Nov 26 12:49:55 display0 systemd[1]: display-firmata.service: Service hold-off time over, scheduling restart.
Nov 26 12:49:55 display0 systemd[1]: Stopped display-firmata.service.
Nov 26 12:49:55 display0 systemd[1]: Started display-firmata.service.
Nov 26 12:49:56 display0 systemd[1]: Started display-status-led.service.
Nov 26 12:49:56 display0 systemd[1]: display-firmata.service: Watchdog timeout (limit 1s)!
Nov 26 12:49:56 display0 systemd[1]: display-firmata.service: Killing process 2690 (python) with signal SIGABRT.
Nov 26 12:49:56 display0 systemd[1]: display-firmata.service: Main process exited, code=killed, status=6/ABRT
Nov 26 12:49:56 display0 systemd[1]: display-firmata.service: Unit entered failed state.
Nov 26 12:49:56 display0 systemd[1]: display-firmata.service: Failed with result 'watchdog'.

Nov 26 12:50:04 display0 systemd[1]: Starting display-status-led.service...
Nov 26 12:50:06 display0 systemd[1]: Started display-status-led.service.
Nov 26 12:50:06 display0 systemd[1]: display-firmata.service: Service hold-off time over, scheduling restart.
Nov 26 12:50:06 display0 systemd[1]: Stopped display-firmata.service.
Nov 26 12:50:06 display0 systemd[1]: Started display-firmata.service.
Nov 26 12:50:08 display0 systemd[1]: display-firmata.service: Watchdog timeout (limit 1s)!
Nov 26 12:50:08 display0 systemd[1]: display-firmata.service: Killing process 2729 (python) with signal SIGABRT.
Nov 26 12:50:08 display0 systemd[1]: display-firmata.service: Main process exited, code=killed, status=6/ABRT
Nov 26 12:50:08 display0 systemd[1]: display-firmata.service: Unit entered failed state.
Nov 26 12:50:08 display0 systemd[1]: display-firmata.service: Failed with result 'watchdog'.

^C
mastensg@display0:~ $
```

`WatchdogSec=30`

```
Nov 26 12:51:00 display0 systemd[1]: Started display-status-led.service.
Nov 26 12:51:24 display0 systemd[1]: Starting display-status-led.service...
Nov 26 12:51:26 display0 systemd[1]: Started display-status-led.service.
Nov 26 12:51:28 display0 systemd[1]: display-firmata.service: Watchdog timeout (limit 30s)!
Nov 26 12:51:28 display0 systemd[1]: display-firmata.service: Killing process 2903 (python) with signal SIGABRT.
Nov 26 12:51:28 display0 systemd[1]: display-firmata.service: Main process exited, code=killed, status=6/ABRT
Nov 26 12:51:28 display0 systemd[1]: display-firmata.service: Unit entered failed state.
Nov 26 12:51:28 display0 systemd[1]: display-firmata.service: Failed with result 'watchdog'.
Nov 26 12:51:34 display0 systemd[1]: Starting display-status-led.service...
Nov 26 12:51:36 display0 systemd[1]: Started display-status-led.service.
Nov 26 12:51:38 display0 systemd[1]: display-firmata.service: Service hold-off time over, scheduling restart.
Nov 26 12:51:38 display0 systemd[1]: Stopped display-firmata.service.
Nov 26 12:51:38 display0 systemd[1]: Started display-firmata.service.
Nov 26 12:51:39 display0 kernel: cdc_acm 1-1.1.2.4:1.0: failed to set dtr/rts
Nov 26 12:51:40 display0 kernel: cdc_acm 1-1.1.2.4:1.0: failed to set dtr/rts
Nov 26 12:51:54 display0 systemd[1]: Starting display-status-led.service...
Nov 26 12:51:56 display0 systemd[1]: Started display-status-led.service.
Nov 26 12:52:04 display0 systemd[1]: Starting display-status-led.service...
Nov 26 12:52:06 display0 systemd[1]: Started display-status-led.service.
Nov 26 12:52:08 display0 systemd[1]: display-firmata.service: Watchdog timeout (limit 30s)!
Nov 26 12:52:08 display0 systemd[1]: display-firmata.service: Killing process 2983 (python) with signal SIGABRT.
Nov 26 12:52:08 display0 systemd[1]: display-firmata.service: Main process exited, code=killed, status=6/ABRT
Nov 26 12:52:08 display0 systemd[1]: display-firmata.service: Unit entered failed state.
Nov 26 12:52:08 display0 systemd[1]: display-firmata.service: Failed with result 'watchdog'.
Nov 26 12:52:14 display0 systemd[1]: Starting display-status-led.service...
Nov 26 12:52:16 display0 systemd[1]: Started display-status-led.service.
Nov 26 12:52:19 display0 systemd[1]: display-firmata.service: Service hold-off time over, scheduling restart.
Nov 26 12:52:19 display0 systemd[1]: Stopped display-firmata.service.
Nov 26 12:52:19 display0 systemd[1]: Started display-firmata.service.
Nov 26 12:52:19 display0 systemd[1]: Starting display-status-led.service...
Nov 26 12:52:20 display0 kernel: cdc_acm 1-1.1.2.4:1.0: failed to set dtr/rts
Nov 26 12:52:21 display0 systemd[1]: Started display-status-led.service.
```

### disable output buffering, to make the journal useful

`ExecStart=/opt/windmachine/venv/bin/python /opt/windmachine/firmware/wp_firmata.py`

into

`ExecStart=/opt/windmachine/venv/bin/python -u /opt/windmachine/firmware/wp_firmata.py`

### watchdog timeout

```
TimeoutStartSec=20
WatchdogSec=2
```

too short watchdog timeout:

```
Nov 26 13:30:28 display0 systemd[1]: display-firmata.service: Service hold-off time over, scheduling restart.
Nov 26 13:30:28 display0 systemd[1]: Stopped display-firmata.service.
Nov 26 13:30:28 display0 systemd[1]: Started display-firmata.service.
Nov 26 13:30:28 display0 python[10508]: Python Version 3.5.3 (default, Sep 27 2018, 17:25:39)
Nov 26 13:30:28 display0 python[10508]: [GCC 6.3.0 20170516]
Nov 26 13:30:28 display0 python[10508]: PyMata version 2.18  Copyright(C) 2013-18 Alan Yorinks    All rights reserved.
Nov 26 13:30:28 display0 python[10508]: Opening Arduino Serial port /dev/ttyACM0
Nov 26 13:30:30 display0 systemd[1]: display-firmata.service: Watchdog timeout (limit 2s)!
Nov 26 13:30:30 display0 systemd[1]: display-firmata.service: Killing process 10508 (python) with signal SIGABRT.
Nov 26 13:30:30 display0 systemd[1]: display-firmata.service: Main process exited, code=killed, status=6/ABRT
Nov 26 13:30:30 display0 systemd[1]: display-firmata.service: Unit entered failed state.
Nov 26 13:30:30 display0 systemd[1]: display-firmata.service: Failed with result 'watchdog'.
```

```
TimeoutStartSec=10
WatchdogSec=10
```

looks good.

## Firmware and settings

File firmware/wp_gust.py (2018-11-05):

#!/usr/bin/env python3

import wp_ipc

import gevent
import gevent.event

import sys
import time
import copy
import random


# Poor-mans dataclasses, since we don't have Python 3.7
class Inputs(): 
  def __init__(self,
        # Actual inputs
        wind_speed  : float = 0.0,
        scale : float = 1.0,
        user_button: bool = False,

        # Parameters
        perturbation_period : float = 1000.0, # milliseconds
        gust_factor_stddev: float = 0.10, # ratio
        noise_period : int = 200,
        idle_duty : float = 0.20, # on ratio
        active_time : float = 15.0,
        min_windspeed : float = 5.0,
        
        time : float = 0.0):

    attrs = locals()
    del attrs['self']
    self.__dict__.update(attrs)

class State():
  def __init__(self,
        fan_duty : float = 0.0,

        user_button_on : bool = False,
        active_mode_end : float = 0.0,
        perturbation : float = 0.0,
        next_perturbation_update : float = 0.0,
        noise = None,
        noise_phase : int = 0 ):

    attrs = locals()
    del attrs['self']
    self.__dict__.update(attrs)


def next_state(current : State, inputs: Inputs):
    state = copy.copy(current)

    if state.noise is None:
        state.noise = [ random.normalvariate(1.0, inputs.gust_factor_stddev) for _ in range(inputs.noise_period) ]

    if inputs.time >= current.next_perturbation_update:
        state.perturbation = state.noise[state.noise_phase]

        state.noise_phase = state.noise_phase + 1 if state.noise_phase < inputs.noise_period - 1 else 0
        state.next_perturbation_update = inputs.time + (inputs.perturbation_period/1000.0)

    # User button -> active mode
    if inputs.user_button:
        state.active_mode_end = inputs.time + inputs.active_time

    # Active mode end
    is_active = current.active_mode_end is not None
    if is_active and inputs.time >= current.active_mode_end:
        state.active_mode_end = None

    state.user_button_on = inputs.user_button

    if is_active:
        wind_speed = inputs.wind_speed * state.perturbation

        # ensure fan turns on for low speeds
        wind_speed = max(inputs.min_windspeed, wind_speed)

        state.fan_duty = (1 / 25) * wind_speed * (3.0 * inputs.scale)
    else:
        state.fan_duty = inputs.idle_duty

    return state

def update_inputs_ipc(inputs, ipc_session):
    published_values = ipc_session.recv()
    for topic, value in published_values.items():
        if "potentiometer" == topic:
            inputs.__dict__['scale'] = value
        if "button" == topic:
            inputs.__dict__['user_button'] = value
        if "wind_speed" == topic:
            inputs.__dict__['wind_speed'] = value

def set_outputs_ipc(ipc_session, state):
    ipc_session.send("fan_duty", state.fan_duty)
    ipc_session.send("is_active", state.active_mode_end is not None)


def main():
    loop_interval = 100
    state = State()
    inputs = Inputs()
    ipc_session = wp_ipc.Session()

    def loop():
        nonlocal state
        inputs.__dict__['time'] = time.time()
        update_inputs_ipc(inputs, ipc_session)

        state = next_state(state, inputs)

        s = copy.copy(state.__dict__)
        del s['noise']
        #print('i', inputs.__dict__)
        #print('s', s)
        sys.stdout.flush()

        set_outputs_ipc(ipc_session, state)

    #print('main')
    result = gevent.event.AsyncResult()
    def run():
        while True:
            loop()
            gevent.sleep(loop_interval/1000)
        result.set('done')

    gevent.spawn(run)
    result.get(timeout=None) # wait forever


if __name__ == '__main__':
    main()

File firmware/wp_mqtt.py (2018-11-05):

#!/usr/bin/env python3

import wp_ipc
import gpio

import gevent.monkey
gevent.monkey.patch_all()

import gevent
import msgflo

import os
import sys
import time
import os.path
import json
import math
import copy
import random

import logging
logging.basicConfig()
log_level = os.environ.get('LOGLEVEL', 'info')
level = getattr(logging, log_level.upper())
log = logging.getLogger('display')
log.setLevel(level)


# Poor-mans dataclasses, since we don't have Python 3.7
class Inputs(): 
  def __init__(self,
        time : float, # seconds
        windspeed  : float, # meters/second
        mqtt_connected : bool = False):

    attrs = locals()
    del attrs['self']
    self.__dict__.update(attrs)

class State():
  def __init__(self,
        wind_speed : float = 0.0):

    attrs = locals()
    del attrs['self']
    self.__dict__.update(attrs)


def next_state(current : State, inputs : Inputs):
  state = State(
    wind_speed = inputs.windspeed,
  )
  return state


participant_definition = {
  'component': 'windmachine/Display',
  'label': 'Demonstrates the power of the wind',
  'icon': 'clock-o',
  'inports': [
    { 'id': 'windspeed', 'type': 'number' },
  ],
  'outports': [
    { 'id': 'error', 'type': 'string' },
    { 'id': 'currentwindspeed', 'type': 'number' },
  ],
}

# Used for testing
class AlwaysErroringParticipant(msgflo.Participant):
  def __init__(self, role):
    d = copy.deepcopy(participant_definition)
    msgflo.Participant.__init__(self, d, role)

  def process(self, inport, msg):
    if inport == 'windspeed':
        self.send('error', "Updating windspeed always fails")
    else:
        self.send('error', 'Unknown port {}'.format(inport))
    self.ack(msg)

class Participant(msgflo.Participant):
  def __init__(self, role):
    d = copy.deepcopy(participant_definition)
    msgflo.Participant.__init__(self, d, role)

    self.windspeed_file = role.replace('/', '_')+'.windspeed.txt'

    self.state = State()
    self.inputs = Inputs(time=0, windspeed=0.0)

    self.ipc_session = wp_ipc.Session()

    gevent.Greenlet.spawn(self.loop)

  def process(self, inport, msg):
    self.recalculate_state(mqtt_windspeed=msg.data)
    self.ack(msg)

  def loop(self):
    while True:
      self.recalculate_state()
      gevent.sleep(1.0)

  def is_connected(self):
    return getattr(self, '_engine', None) and self._engine.connected

  def set_outputs(self, state : State):
    outputs = {
      'wind_speed': state.wind_speed,
    }
    #print('TODO: realize outputs', outputs)
    for k, v in outputs.items():
      self.ipc_session.send(k, v)

  def get_inputs(self) -> Inputs:
    windspeed = 0.0
    try:
      with open(self.windspeed_file, 'r') as f:
        windspeed = float(f.read())
    except FileNotFoundError:
      pass
    except ValueError as e:
      logging.warning("Error reading windspeed file, removing. " + str(e))
      os.remove(self.windspeed_file)

    got = self.ipc_session.recv(timeout_ms=5)
    #print('g', got)

    inputs = Inputs(
        time=time.monotonic(),
        mqtt_connected=self.is_connected(),
        windspeed=windspeed,
    )
    return inputs

  def recalculate_state(self, mqtt_windspeed=None):

    if mqtt_windspeed:
      # Got new update, write it to disk
      with open(self.windspeed_file, 'w') as f:
        f.write(str(mqtt_windspeed))

      if self.is_connected():
        self.send('currentwindspeed', mqtt_windspeed) 

    inputs = self.get_inputs()
    next = next_state(copy.deepcopy(self.state), copy.deepcopy(inputs))
    self.set_outputs(next)

    state_changed = next != self.state
    if state_changed:
      entry = { 'inputs': inputs.__dict__, 'state': next.__dict__ }
      #log.info(entry)

    self.state = next
    self.inputs = inputs

def main():
    role = os.environ.get('DISPLAY_PREFIX', 'display/X')
    if len(sys.argv) >= 2:
      role = sys.argv[1]
    p = msgflo.main(Participant, role=role)

if __name__ == '__main__':
    main()

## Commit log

2018-10-05 Add pwm2analog board
2018-10-09 firmware: Some testing code for fan control
    Blinky works with Uno, but Uno restarts on each boot,
    and pyfirmata is entirely undocumented
2018-10-09 firmware: Update to use PWM on pyMata
2018-10-09 Found 4G modem with external antenna
2018-10-16 Add baseboard for lasercutting
    [baseboard-1.dxf, baseboard.fcstd]
2018-10-18 parts: add power supply for monitor
2018-10-19 firmware/gust_gui: animation controls and fan flow simulation
2018-10-22 parts: toggle switch
2018-10-22 Fix perturbation amplitude not being read
    [gust_gui.py]
2018-10-23 Clamp fan dutycycle
2018-10-23 parts: power supply box
2018-10-29 electronics/psu: power supply base board
    [psu.dxf, psu.fcstd]
2018-10-29 electronics/block_diagram: add power supply and arduino button
2018-10-29 firmware: Add support for user/front button
2018-10-29 Make user button enter active mode for N seconds
2018-10-30 Update SIM pin
2018-11-02 firmware/set_button: emulate front button
2018-11-02 firmware/wp_status: print statuses on standard output
2018-11-02 firmware/wp_status: moden [vp]id, mmcli, control leds
2018-11-02 firmware/wp_status: fix led pin mapping, ping to check hub connection
2018-11-02 ansible/ssh-call-home-device: enable StreamLocalBindUnlink
    see: https://unix.stackexchange.com/a/429903
2018-11-02 ansible/ssh-call-home-device: revert unhelpful StreamLocalBindUnlink
